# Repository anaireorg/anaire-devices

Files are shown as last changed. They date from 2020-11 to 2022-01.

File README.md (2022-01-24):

# Dispositivos ANAIRE: medidores de CO2 (NDIR), temperatura y humedad

**Enlace al medidor** [ *Anaire PiCO2*](https://github.com/anaireorg/anaire-devices/blob/main/Anaire.PiCO2/README.md)

---

[**Anaire**](http://www.anaire.org) - Somos un equipo de ingenieros españoles con la vocación de difundir de forma gratuita el conocimiento tecnológico que permita facilitar al máximo la monitorización del CO2 y contribuir así a la protección frente al contagio de COVID-19.

Diseñamos **medidores de CO2, temperatura y humedad**, optimizados para que cualquiera se los pueda fabricar por sí mismo y **aplicaciones hospedadas en la nube** para facilitar la monitorización de las medidas y la generación de alarmas que puedan alertar a la gente cuando los niveles de CO2 superen los umbrales de seguridad.

<p align="center">
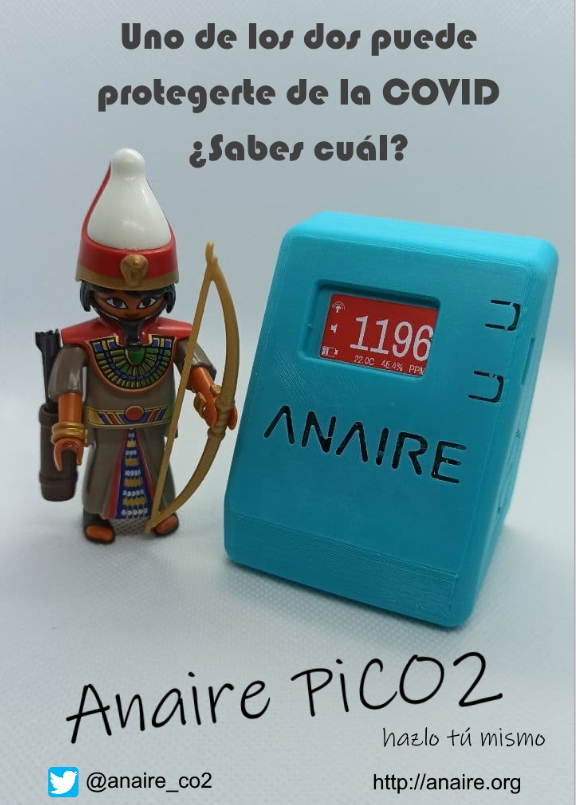
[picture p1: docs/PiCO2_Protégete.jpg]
  
</p>  

Nuestros dispositivos tienen las siguientes características principales:

- **Open source**, es decir, toda la información para su fabricación, tanto *hardware* como *software*, está disponible para su uso y modificación de acuerdo a los términos de la [licencia](LICENSE.md), siendo en todo momento totalmente gratuitos.

- Basados en sensores de CO2 de [*tecnología NDIR*](https://es.wikipedia.org/wiki/Sensor_de_Infrarrojo_No_Dispersivo), de bajo coste y alta precisión.

- **Hazlo tú mismo:** Fabricación muy sencilla, con mecanización mediante cajas fabricadas por impresión 3D para el alojamiento de los distintos componentes y su conexión mediante cables Dupont, minimizando el número de soldaduras necesarias.

- Conectados por WiFi a la [*aplicación en la nube Anaire Cloud*](https://github.com/anaireorg/anaire-cloud) para mostrar los valores instantáneos y el histórico de mediciones de CO2, temperatura y humedad, facilitando así el análisis de la información de las medidas y su correlación con protocolos de ventilación anti COVID-19, así como automatizaciones en forma de alarmas u otros eventos automáticos en función del valor de las medidas.

<p align="center">
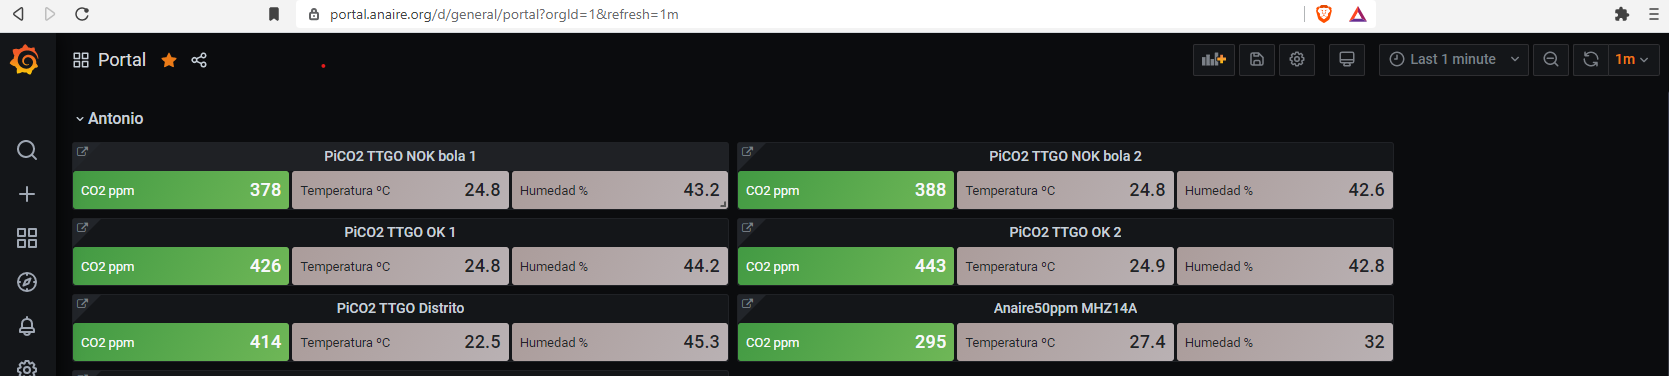
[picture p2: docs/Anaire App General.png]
  
</p>

<p align="center">
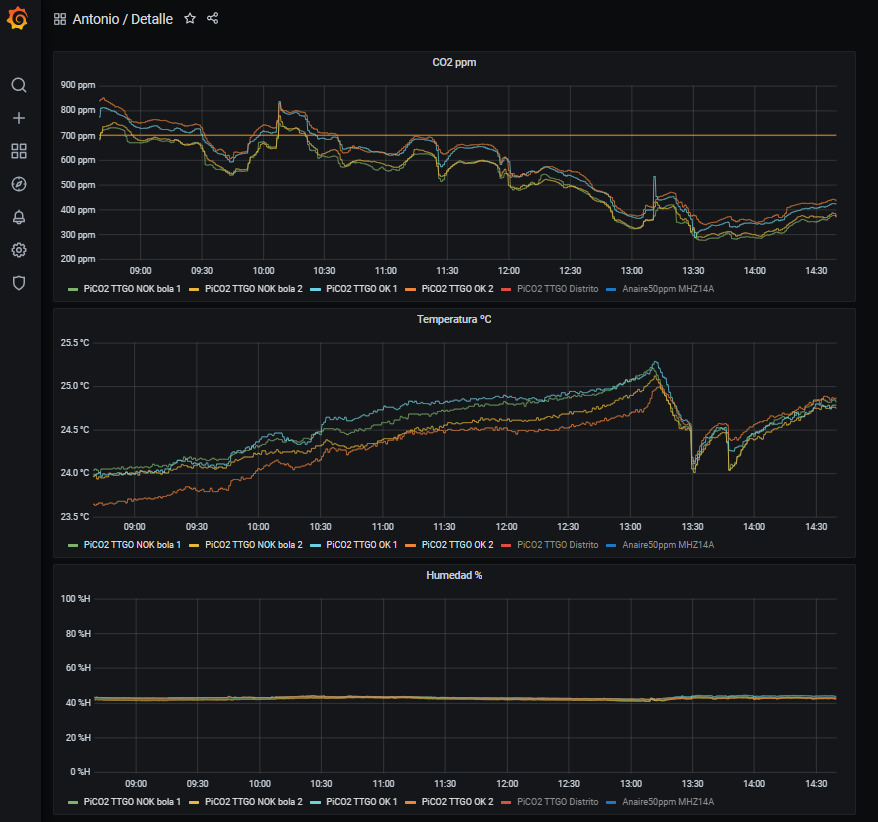
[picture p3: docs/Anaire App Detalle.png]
  
</p>

Hemos diseñado y documentado en detalle los siguientes dispositivos:

- [*Anaire PiCO2*](https://github.com/anaireorg/anaire-devices/blob/main/Anaire.PiCO2/README.md)
Nuestro último modelo, basado en el sensor de alta gama [*Sensirion SCD30*](https://www.sensirion.com/en/environmental-sensors/carbon-dioxide-sensors/carbon-dioxide-sensors-scd30/), con precición de 30 PPM (partes por millón), alarma acústica, pantalla a color y batería recargable mediante USB-C, lo que permite su uso portátil.
- [*Anaire 30/50ppm*](https://github.com/anaireorg/anaire-devices/blob/main/Anaire.30ppm-50ppm/README.md)
Nuestro primer dispositivo, con dos opciones: **Anaire 30ppm**, también basado en el mismo sensor [*Sensirion SCD30*](https://www.sensirion.com/en/environmental-sensors/carbon-dioxide-sensors/carbon-dioxide-sensors-scd30/), y **Anaire 50ppm**, que equipa el sensor [*Winsen MHZ14A*](https://www.winsen-sensor.com/sensors/co2-sensor/mh-z14a.html), de menor coste pero también menor precisión (50 PPM) y mayor tiempo de respuesta. Ambos modelos con alarma acústica, pantalla monocroma y alimentación mediante MicroUSB.

En este repositorio se publica información completa para la fabricación de los distintos modelos de medidor de CO2 Anaire, desde el código fuente hasta las especificaciones de componentes, cableados y opciones de montaje tanto en placa de prototipado como utilizando cajas de impresión 3D para la colocación de los componentes. La intención es que cualquier persona pueda encontrar aquí la información necesaria y suficiente para montar su propio sensor de CO2, con o sin conexión a la nube, sin necesidad de grandes conocimientos técnicos, como ayuda para combatir la pandemia causada por la COVID-19, contribuyendo así a preparar entornos más seguros, con mínimos niveles de CO2, que ayuden a prevenir contagios en entornos cerrados.

Toda la información se publica en formato *open source*, tanto los diseños hardware como el software (código fuente), con el ánimo de facilitar el uso y difusión de la tecnología todo lo posible. Con el mismo espíritu se tratan de resolver todas las incidencias reportadas en todos los canales donde la asociación está presente:

Página web: www.anaire.org  
Correo electrónico: anaire@anaire.org  
Canal de Youtube: https://www.youtube.com/c/AnaireCO2  
Twitter: @Anaire_co2  
Instagram: anaire_co2  
Facebook: @anaireco2  

---  

# Características detalladas

<p align="center">
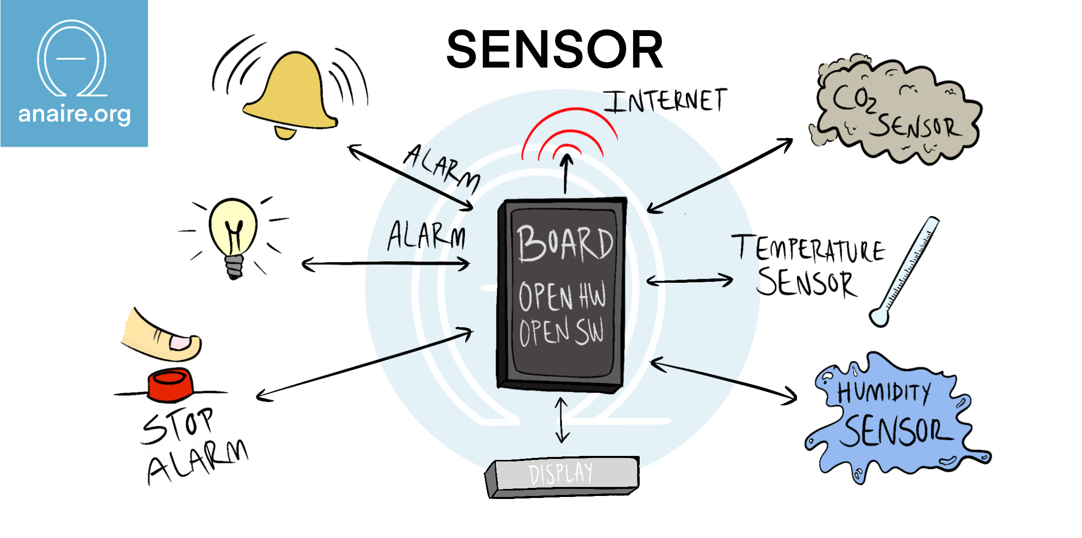
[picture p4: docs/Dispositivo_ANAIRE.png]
  
</p>  

* Medición de CO2 mediante sensores NDIR de alta precisión cada 5 o 10 segundos (Anaire 30/50ppm y Anaire PiCO2 respectivamente).
  * Adicionalmente se realizan de forma simultánea mediciones de temperatura y de humedad.
  * Cada 30 segundos las medidas se envían a la aplicación en la nube y pueden ser visualizadas en [portal.anaire.org](http://portal.anaire.org).
* Completamente open source, tanto hardware como software. Toda la información, tanto sobre este dispositivo como sobre la aplicación en la nube con la que se comunica, está disponible en los [repositorios de Anaire en github](https://github.com/anaireorg). Sin excepciones.  
* Alarma local, visual y acústica, cuando el nivel de CO2 sobrepasa los umbrales de aviso y alarma. Estos umbrales están fijados por defecto en 700ppm y 1.000ppm, pero los valores son configurables para cada dispositivo a través de la aplicación en la nube.
* La alarma acústica puede conmutarse localmente (encendido/apagado) mediante un botón en el dispositivo, desde el servidor web o desde la configuración del dispositivo en la nube.  
* Gestión de múltiples características de los dispositivos a través de los dos botones que equipan.
* Conexión a una red WiFi para el envío de las medidas a una aplicación desplegada en la nube con objeto de obtener los siguientes beneficios adicionales:
  * Monitorizar las medidas a través de internet desde cualquier tipo de dispositivo conectado.
  * Agregar la información de múltiples dispositivos permitiendo visualizar de forma simultánea el estado de todos ellos, siguiendo un código de colores sencillo (verde, amarillo y rojo) para indicar el estado actual de una organización con múltiples dispositivos. La idea es, sobre todo, poder monitorizar la medida del CO2 en centros de enseñanza, donde alumnos y profesores deben compartir espacios cerrados cotidianamente y durante periodos extendidos de tiempo.
  * Almacenar las medidas de CO2, temperatura y humedad durante al menos 15 días.
  * Facilitar el análisis de las medidas almacenadas, permitiendo el acceso al histórico de medidas de forma sencilla, para de este modo facilitar el análisis del funcionamiento de los protocolos de ventilación.  
  * Generar alarmas que puedan alertar a los responsables de una organización cuando los niveles de CO2 en cualquiera de los espacios gestionados alcancen valores peligrosos para la salud.
* Toda la información almacenada en la nube es accesible vía Internet, tanto en modo individual para cada dispositivo como en modo agregado en cuadros de mandos configurables con usuarios y permisos de visualización y de edición arbitrarios. De este modo se pueden definir distintos tipos de usuarios con distintos niveles de visualización de la información: personal del centro, alumnos, padres de alumnos, equipos de prevención de riesgos laborales, etc.  
* Para el acceso a la información sólo es preciso un dispositivo con conexión a Internet (ordenador, teléfono móvil, tableta, etc.), la dirección de acceso al dispositivo o a la organización, y un usuario y contraseña (en caso de que se hayan habilitado políticas de acceso).  
* Comunicación entre el dispositivo y la aplicación en la nube mediante protocolo MQTT.  
* Fabricación sencilla, soldando únicamente los cuatro pines necesarios en el sensor de CO2 y conectando los componentes mediante cables Dupont.
* Mecanización basada en cajas diseñadas a medida y fabricadas mediante impresoras 3D, que permiten ubicar de forma robusta los distintos componentes en los espacios preparados para ello en la caja. La caja es compatible para los distintos sensores, y alberga adicionalmente el display y el resto de los componentes de forma que sea muy fácil la lectura de las medidas.
* Alimentación mediante cables USB conectados a cualquier fuente de alimentación que proporcione más de 1A de corriente:
  * Cables MicroUSB en el caso de los dispositivos Anaire 30/50ppm
  * Cables USB-C para los dispositivos PiCO2
* Actualización remota de parámetros desde la aplicación en la nube:
  * Nombre del dispositivo
  * Umbral de aviso (700 ppm por defecto)
  * Umbral de alarma (1.000 ppm por defecto)
  * Activación y desactivación de la alarma acústica (activada por defecto)
  * Ajuste de offset de temperatura del sensor de CO2 (sólo para el Sensirion SCD30)
  * Ajuste de altitud del sensor de CO2 (sólo para el Sensirion SCD30)
  * Valor de referencia para la calibración forzada (420 ppm por defecto)
  * Realización de la calibración forzada
  * Activación y desactivación del mecanismo de autocalibración del sensor de CO2 (sólo para el Sensirion SCD30)
  * Actualización remota de *software* a la última versión disponible en este repositorio
  * Reinicio remoto del dispositivo
  * Restauración de todos los parámetros a los valores por defecto
  * Configuración de la dirección del servidor MQTT (url y puerto)
* Servidor Web desde donde se puede visualizar múltiples parámetros del dispositivo (versión de *software*, sensor equipado, etc.) e incluso realizar operaciones como la calibración de referencia.
* Portal cautivo para la configuración de la red WiFi, accesible mediante un botón en el dispositivo o desde el servidor web.

---

Recursos
---------

* [El País - Un salón, un bar y una clase: así contagia el coronavirus en el aire](https://elpais.com/ciencia/2020-10-24/un-salon-un-bar-y-una-clase-asi-contagia-el-coronavirus-en-el-aire.html)
* [Ventilando](http://www.ventilando.org/)
* [Comunidad de Madrid: Ventilación, climatización y COVID-19](https://www.comunidad.madrid/servicios/salud/ventilacion-climatizacion-covid-19)
* [Guía para ventilación de las aulas del CSIC](https://digital.csic.es/handle/10261/221538)
* [Transmisión de la COVID-19 por el aire (aerosoles). Por José Luis Jiménez.](https://www.youtube.com/watch?v=uI8ODCxrNMU&t=4s)
* [José Luis Jiménez, El País: La covid se transmite a través de aerosoles: ya es el momento de actuar, tenemos suficientes pruebas](https://elpais.com/ciencia/2020-08-18/la-covid-se-transmite-a-traves-de-aerosoles-ya-es-el-momento-de-actuar-tenemos-suficientes-pruebas.html)
* [Summary of the Evidence For and Against the Routes of Transmission of SARS-CoV-2](https://docs.google.com/presentation/d/11rY9tQtkFaV_M4N-hf5qp1_Xtuw8JYb4Qvv5e7BEmcc/edit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)
* [Aireamos: Medidores de CO2 disponibles en España](https://www.aireamos.org/medidores/)
* [Así se ven los aerosoles en un ascensor, una tienda, una oficina y un bar: ¿cómo se transmite el coronavirus?](https://amp.rtve.es/noticias/20210312/coronavirus-aerosoles-imagenes/2081740.shtml)
* [Daily global CO2](https://www.esrl.noaa.gov/gmd/ccgg/trends/gl_trend.html)
* [IAQ Rating Index](http://www.iaquk.org.uk/ESW/Files/IAQ_Rating_Index.pdf)

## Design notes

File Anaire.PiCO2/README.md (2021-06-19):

# Anaire PiCO2

*@2021 Anaire www.anaire.org*

---

<p align="center">
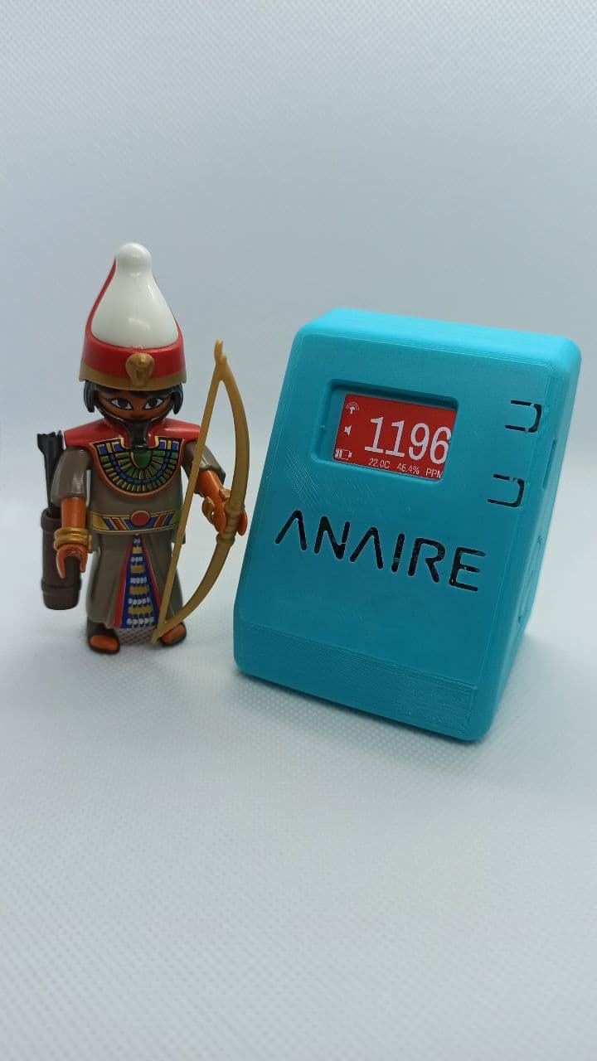
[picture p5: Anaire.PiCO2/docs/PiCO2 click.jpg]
  
</p>  

# Tabla de contenidos
[1. Hardware](#id1)  
[2. Software](#id2)  
[3. Fabricación](#id3)  
[4. Configuración](#id4)  
[5. Uso](#id5)  
[6. Diagnóstico](#id6)  

---

# 1. Hardware

El medidor Anaire PiCO2 es un dispositivo basado en un microcontrolador ESP32 en una tarjeta de control [LILYGO® TTGO T-Display ESP32 WiFi And Bluetooth](https://github.com/Xinyuan-LilyGO/TTGO-T-Display), que proporciona también conectividad WiFi y Bluetooth, y permite su programación desde el IDE de Arduino. La tarjeta tiene integrado un display en color para mostrar las mediciones e indicaciones de estado. Adicionalmente el dispositivo equipa un zumbador para poder emitir alertas sonoras y una batería recargable para facilitar la movilidad.

Para realizar las medidas se conecta un sensor de CO2 de tecnología NDIR, que adicionalmente realiza medidas de temperatura y humedad:  [*Sensirion SCD30*](https://www.sensirion.com/en/environmental-sensors/carbon-dioxide-sensors/carbon-dioxide-sensors-scd30/). El Sensirion SCD30 es un sensor de alta calidad y gran velocidad de reacción: tiene mayor precisión que la mayoría de los sensores de su mismo tipo, 30 ppm frente a los 50 ppm del Winsen MH-Z14A; incorpora sensor de temperatura y humedad, con lo que no hay que añadir un sensor adicional para medir temperatura y humedad, facilitando el montaje del medidor. Además de permitir mecanismos de compensación por altitud y temperatura; tiene un mecanismo de autocalibración más robusto, que hace uso de las mediciones de los últimos 30 días, en lugar de las últimas 24 horas, como en el caso del MH-Z14A. Su respuesta es también más rápida ante cambios atmosféricos (por ejemplo, al introducir ventilación en un espacio cerrado). Los inconvenientes del Sensirion SCD30 son que tiene un precio más elevado, que es más frágil durante su manipulación y que tiene menos opciones de compra y, normalmente, mayores plazos de entrega. Para comprar el Sensirion SCD30 hay que recurrir normalmente a plataformas especializadas en componentes electrónicos.

La alimentación del dispositivo se realiza directamente a través del puerto USB-C de la tarjeta de control [LILYGO® TTGO T-Display ESP32 WiFi And Bluetooth](https://github.com/Xinyuan-LilyGO/TTGO-T-Display), el mismo que se utiliza para programarla y para comunicarse con ella. La batería incorporada se carga automáticamente cuando se conecta un cable USB-C alimentado. Se recomienda utilizar fuentes de alimentación (enchufes USB, puertos USB en ordenadores, etc.) que puedan proporcionar al menos 1.000 mA.   

A continuación, se enumeran los elementos citados:

* Tarjeta de control basada en microcontrolador ESP32 [LILYGO® TTGO T-Display ESP32 WiFi And Bluetooth](https://github.com/Xinyuan-LilyGO/TTGO-T-Display)  

<p align="center">
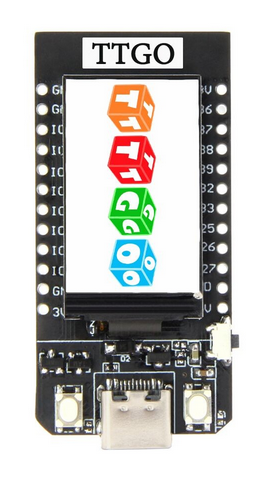
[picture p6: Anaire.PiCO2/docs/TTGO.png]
    
</p>

* Sensor de CO2, temperatura y humedad [*Sensirion SCD30*](https://www.sensirion.com/en/environmental-sensors/carbon-dioxide-sensors/carbon-dioxide-sensors-scd30/). Para la conexión del sensor de CO2 es preciso conectar 4 pines y soldarlos en las posiciones indicadas en el proceso de fabricación. Se pueden comprar pines como [los que aparecen en este enlace](https://www.amazon.es/Pin-Header-Way-Straight-Pitch/dp/B00QXBRCKG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), por ejemplo, y cortar trozos de 4 pines con un alicate de corte o unas tijeras.

<p align="center">
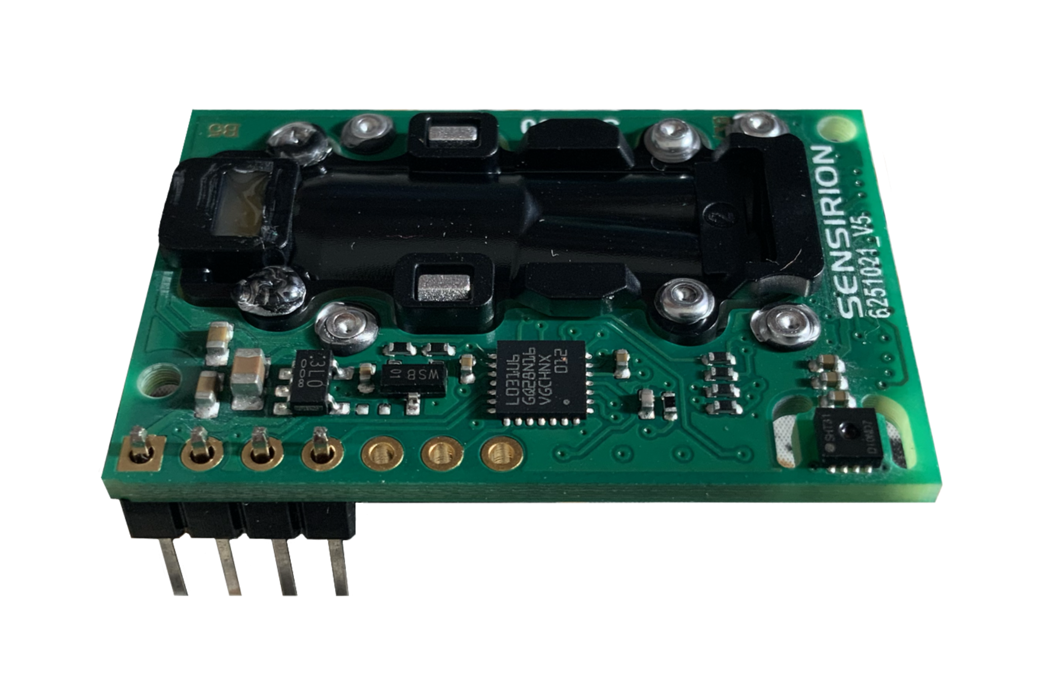
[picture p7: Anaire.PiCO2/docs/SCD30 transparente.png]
  
</p>  

* Caja -Anaire Box- para impresora 3D. Los ficheros para la impresión se pueden encontrar en [este enlace](https://www.thingiverse.com/thing:4854504).

<p align="center">
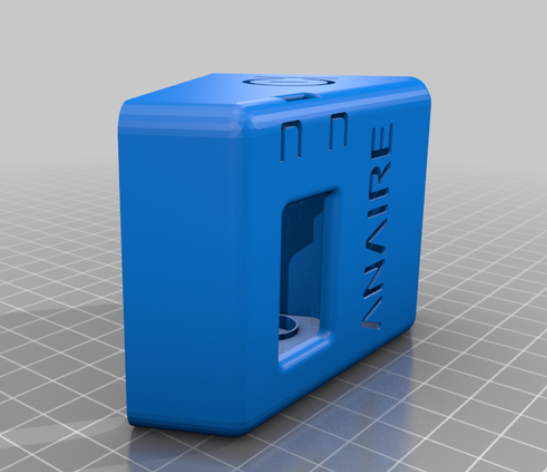
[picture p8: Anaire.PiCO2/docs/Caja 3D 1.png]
  
</p>    
<p align="center">
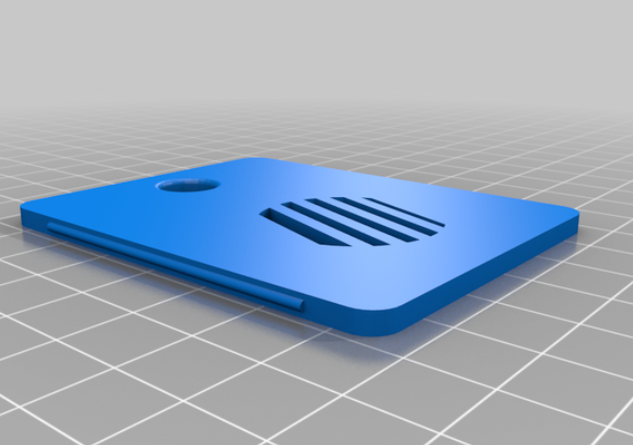
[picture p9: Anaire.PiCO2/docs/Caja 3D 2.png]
  
</p>
<p align="center">
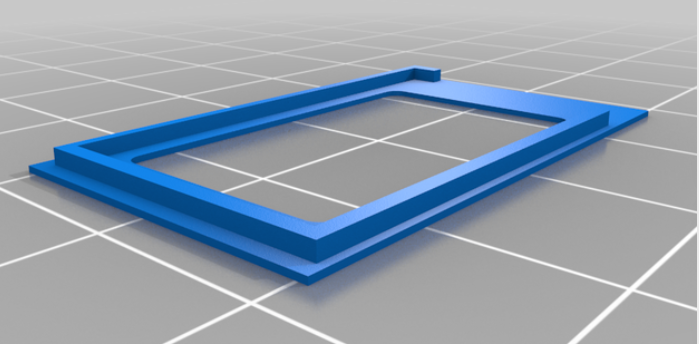
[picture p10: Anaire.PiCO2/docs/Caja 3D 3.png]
  
</p>  

* Zumbador [- AZDelivery Active Buzzer](https://www.az-delivery.de/es/products/buzzer-modul-aktiv?_pos=2)  

<p align="center">
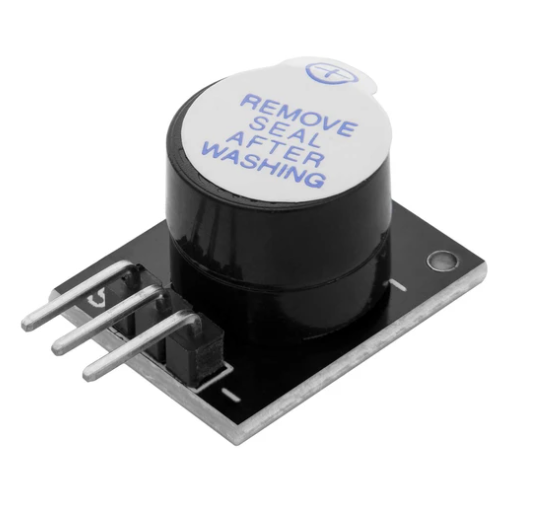
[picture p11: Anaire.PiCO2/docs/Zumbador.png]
    
</p>

* [Batería Recargable de Litio con conector Micro JST 1.25 3.7V y al menos 1.000 mAh de capacidad](https://www.amazon.es/dp/B087LTZW61/ref=cm_sw_r_cp_awdb_imm_BPVY2QA8X3P5GB9NQ55C)

<p align="center">
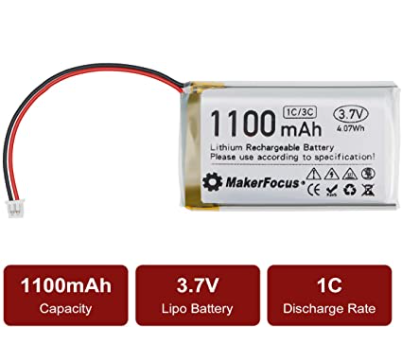
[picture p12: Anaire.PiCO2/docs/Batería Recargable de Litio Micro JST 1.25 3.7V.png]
  
</p>

* [Cables Dupont hembra-hembra de 10cm de longitud](https://es.aliexpress.com/item/32223527499.html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)

<p align="center">
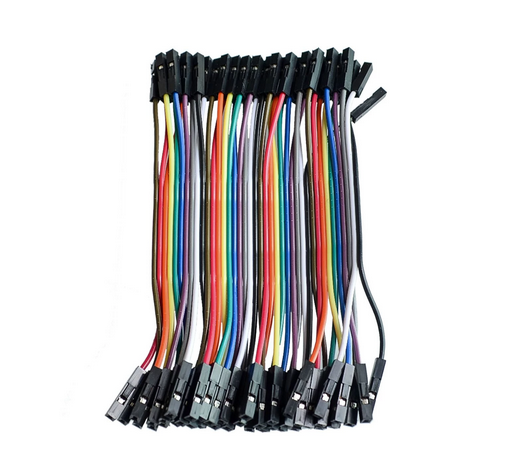
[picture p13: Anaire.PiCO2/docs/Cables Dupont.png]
  
</p>

* Será necesario un cable válido para conectar desde un puerto USB del ordenador al puerto Micro USB-C de la tarjeta TTGO T-Display, para poder cargar el software del dispositivo. Este mismo cable puede ser utilizado para la alimentación eléctrica desde un ordenador, o desde un enchufe USB o incluso desde una batería portátil USB. También podría utilizarse, una vez cargado el software, cualquier otro tipo de dispositivo que tenga un conector USB-C y proporcione al menos 1.000 miliamperios. Por ejemplo, [este cable](https://www.amazon.es/dp/B01N4OKUB8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), o [este alimentador](https://www.amazon.es/UGREEN-Cargador-Delivery-Ultrarrapido-iPhone/dp/B07QRQTKCZ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)

# 2. Software

El software se puede cargar en el dispositivo de dos formas: 

- Utilizando el [entorno de desarrollo (IDE) de Arduino](https://www.arduino.cc/en/software), exactamente igual que una tarjeta arduino. Hay que instalar algunos componentes de software adicionales en el entorno de Arduino, principalmente diversas librerías. La descripción completa de la instalación del entorno de *software* se puede encontrar al inicio del archivo de código fuente del dispositivo medidor [anaire.PiCO2.ino](https://github.com/anaireorg/anaire-devices/blob/main/Anaire.PiCO2/anaire.PiCO2/anaire.PiCO2.ino).

- Mediante un mecanismo sencillo basado en la carga del binario ya compilado en la tarjeta TTGO T-Display, como se describe más adelante, en el apartado de fabricación.

En cualquier caso, la instalación del entorno completo de desarrollo no será necesaria si no se requiere hacer modificaciones en el software. 

Para cualquiera de las dos opciones será necesario instalar previamente en un ordenador con sistema operativo Windows10 el [driver USB-UART](https://www.silabs.com/developers/usb-to-uart-bridge-vcp-drivers) (conversión USB a puerto serie) para poder comunicarse con la tarjeta TTGO T-Display.

# 3. Fabricación

El montaje que se propone pretende simplificar al máximo el proceso de fabricación, manteniendo las máximas prestaciones técnicas. Los componentes se encajan en la caja de impresión 3D, y las conexiones se realizan mediante cables Dupont hembra-hembra, minimizando así las necesidades de soldadura. Sólo será necesario soldar 4 pines en el sensor SCD30 y 7 pines en la tarjeta TTGO T-Display (en el caso de que no se haya comprado con los pines ya soldados).

## Esquema de conexiones:  
<p align="center">
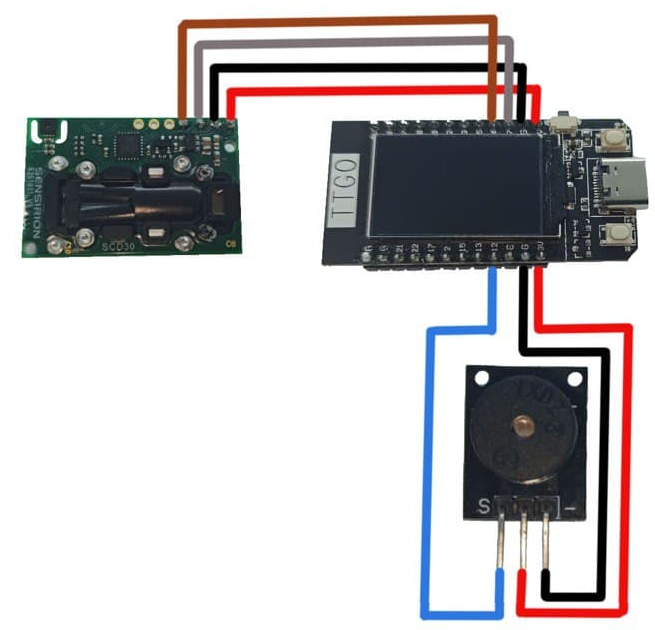
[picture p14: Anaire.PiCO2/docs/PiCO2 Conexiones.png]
  
</p>  

## Detalle del sensor SCD30  
Hay que soldar 4 pines como se muestra en la siguiente imagen  
<p align="center">
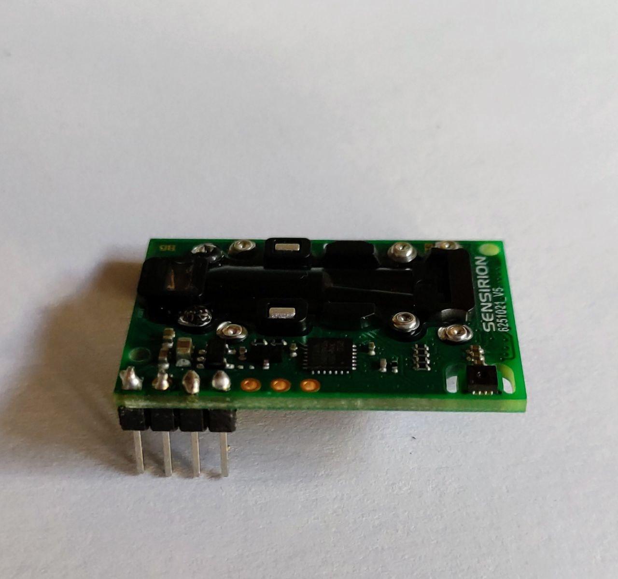
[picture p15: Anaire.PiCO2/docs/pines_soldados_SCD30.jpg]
  
</p>  

## Montaje final  

Recomendamos que primero se conecten los componentes, se cargue el *software*, siguiendo las instrucciones del apartado siguiente, y se verifique así el funcionamiento del medidor.

<p align="center">
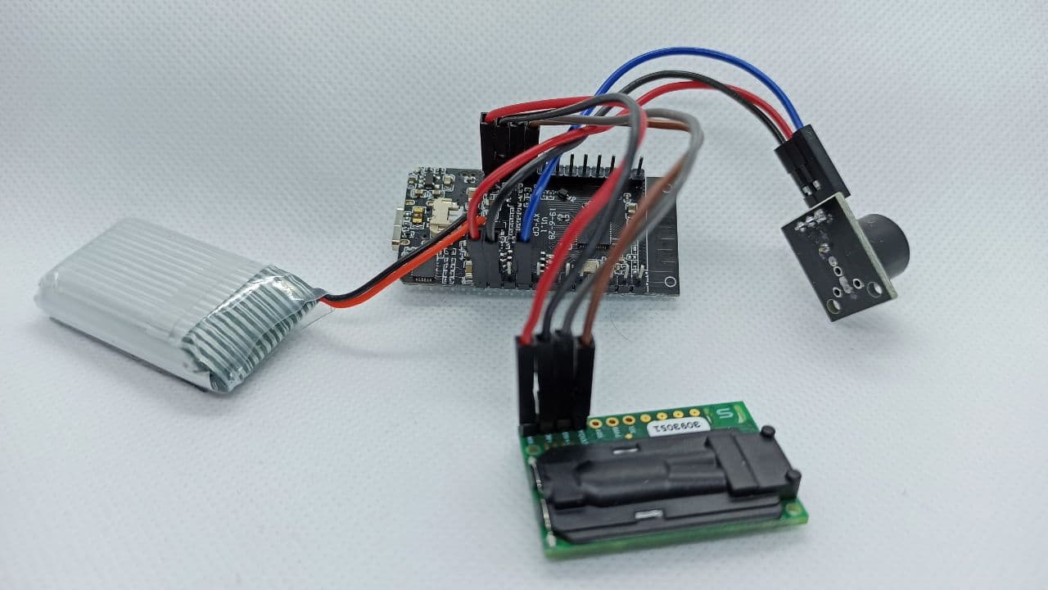
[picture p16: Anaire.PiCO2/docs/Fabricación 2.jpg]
  
</p>  
<p align="center">
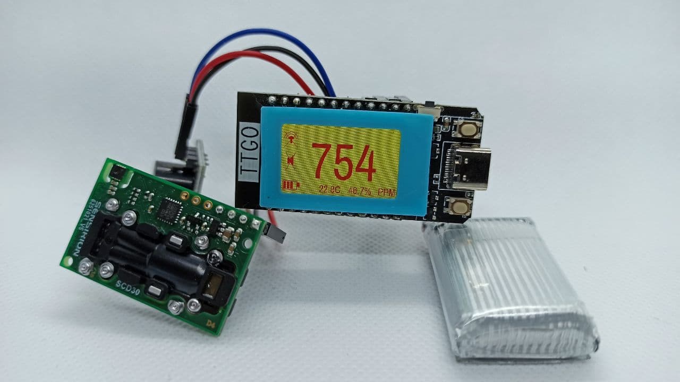
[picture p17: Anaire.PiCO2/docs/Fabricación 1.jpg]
  
</p>  

A continuación, se colocan los componentes mecánicamente en su posición dentro de la caja, y se vuelve a verificar el funcionamiento correcto.

Para ello, primero se coloca la pieza cuadrada pequeña alrededor de la pantalla, como se muestra en la imagen:

<p align="center">
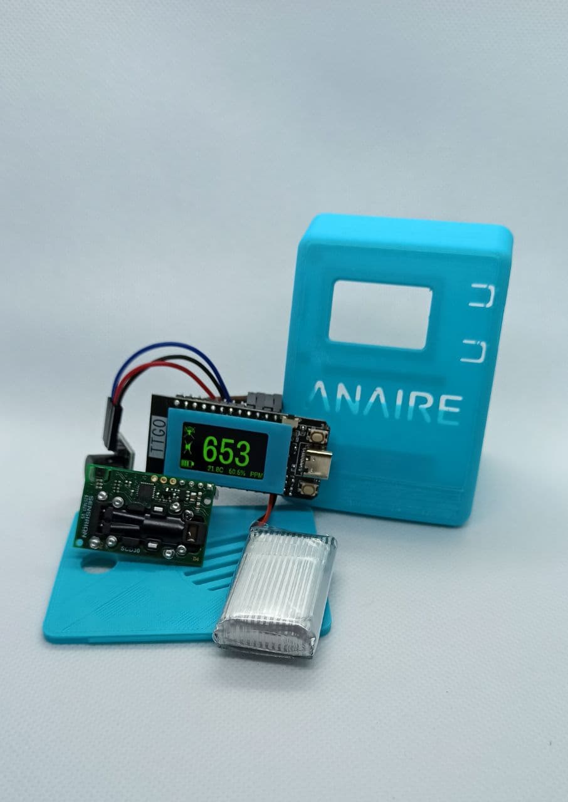
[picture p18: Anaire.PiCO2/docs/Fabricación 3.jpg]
  
</p>

Luego, se inserta la placa ajustando el conector para la alimentación y se encaja en la pestaña que hay en el lado opuesto. Se ajusta el zumbador en el hueco circular del lateral y, finalmente, se ajusta el sensor en las pestañas que hay debajo de donde va colocada la placa.

<p align="center">
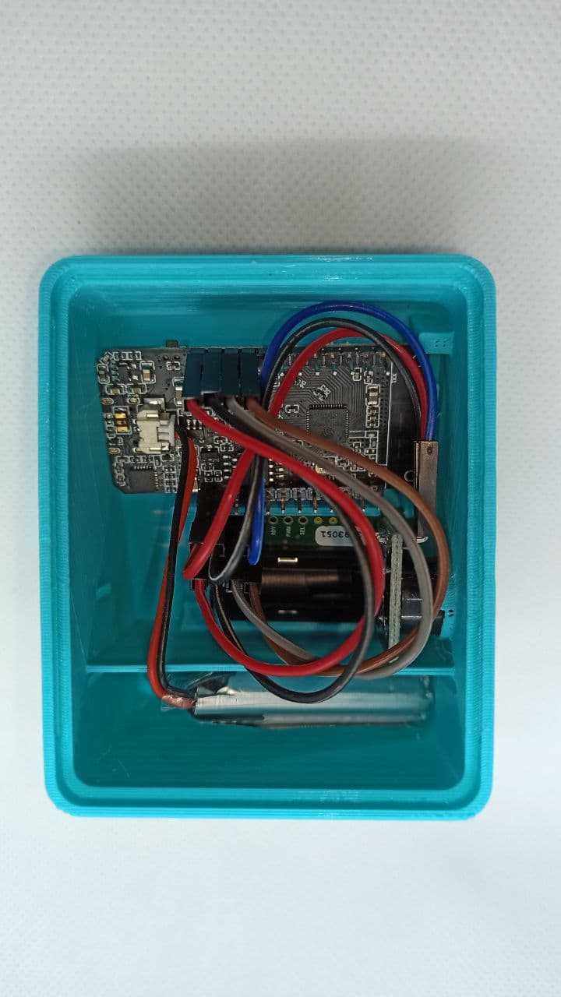
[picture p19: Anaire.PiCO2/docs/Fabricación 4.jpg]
  
</p>

Finalmente se debe proceder a la conexión a la red WiFi y la calibración de referencia del sensor. Se puede activar el mecanismo de autocalibración del SCD30, pero para que funcione correctamente hay que tenerlo encendido durante una semana garantizando su exposición al aire libre (se trata de medir un valor mínimo de CO2) durante al menos una hora al día.

El siguiente vídeo muestra de forma detallada el proceso montaje:

Montaje Anaire PiCO2 (https://youtu.be/GUXPi4h12Kw)

## Carga del software

Para la carga del software hay dos opciones: carga del binario compilado, o carga desde el código fuente. Como ya se ha explicado anteriormente, si no se desea modificar el software se recomienda la primera opción, ya que es mucho más sencilla y rápida.

En cualquiera de los dos casos es preciso instalar previamente en un ordenador con sistema operativo Windows 10 el [driver USB-UART](https://www.silabs.com/developers/usb-to-uart-bridge-vcp-drivers) (conversión USB a puerto serie) para poder comunicarse con la tarjeta TTGO T-Display.

### Carga del binario compilado
Estas instrucciones son únicamente válidas para ordenadores con el sistema operativo Windows 10.

Asegure que se tiene en un directorio los siguientes archivos, disponibles en la carpeta [anaire.PiCO2](https://github.com/anaireorg/anaire-devices/tree/main/Anaire.PiCO2/anaire.PiCO2):
  * anaire.PiCO2.ino.esp32.bin
  * boot_app0.bin
  * bootloader_qio_80m.bin
  * esptool.exe
  * flash_device.bat

Ejecute los siguientes pasos en esa carpeta:
1. Conecte el medidor PiCO2 al ordenador mediante un cable USB-C. En el administrador de dispositivos de windows podrá identificar el puerto COM asignado por el sistema operativo al medidor PiCO2.

<p align="center">
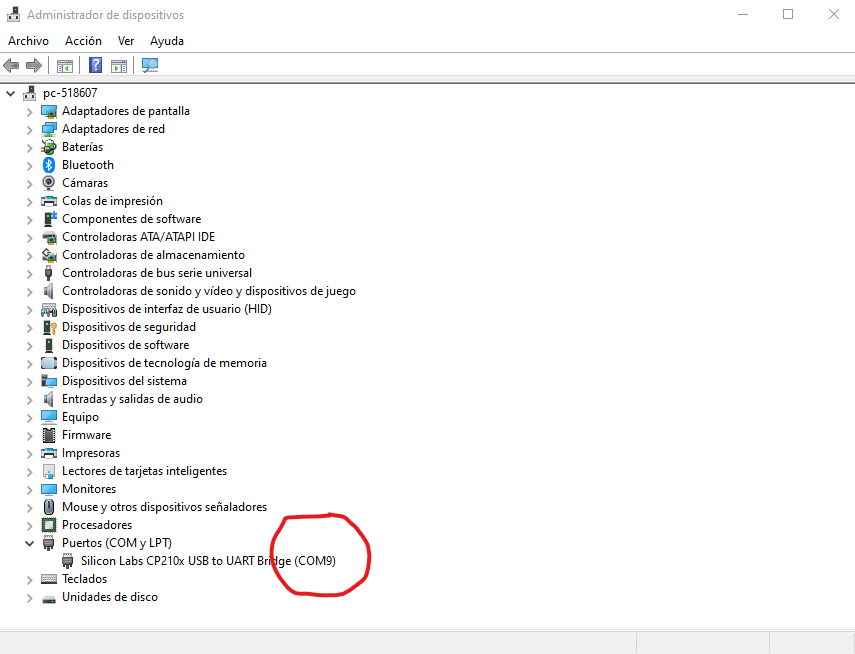
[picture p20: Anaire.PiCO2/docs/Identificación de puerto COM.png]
  
</p>

2. Haga click derecho en el archivo [flash_device.bat](https://github.com/anaireorg/anaire-devices/blob/main/Anaire.PiCO2/anaire.PiCO2/flash_device.bat) y seleccione la opción de *editar*

3. Donde pone *--port COMXX* sustituya el puerto COMXX para poner el que haya identificado previamente en el paso 1, seleccione *archivo->guardar* y cierre la ventana

<p align="center">
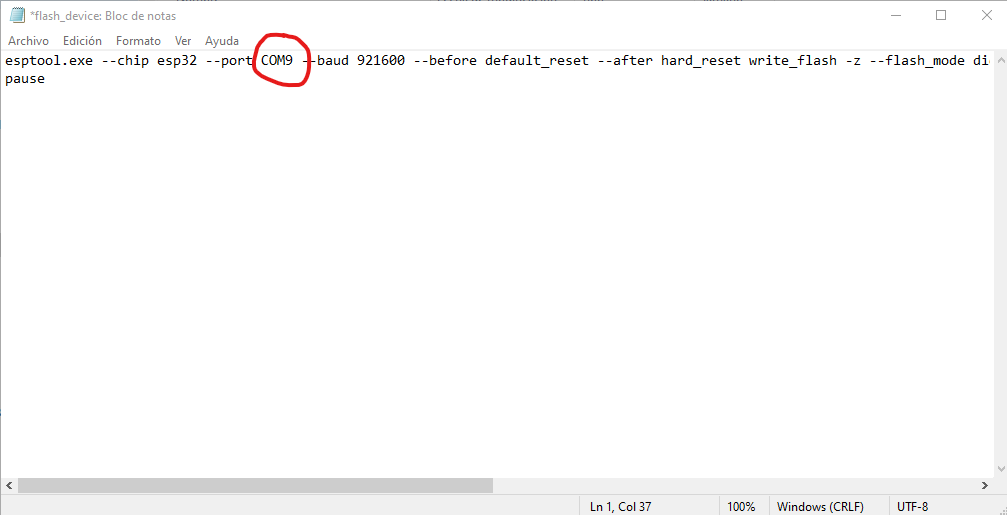
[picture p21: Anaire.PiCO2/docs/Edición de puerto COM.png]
  
</p>

4. Haga doble click en el archivo [flash_device.bat](https://github.com/anaireorg/anaire-devices/blob/main/Anaire.PiCO2/anaire.PiCO2/flash_device.bat). Al acabar la ejecución pedirá que se pulse cualquier tecla para cerrar la ventana. El medidor PiCO2 arrancará con la última versión de *software* disponible en el archivo [anaire.PiCO2.ino.esp32.bin](https://github.com/anaireorg/anaire-devices/blob/main/Anaire.PiCO2/anaire.PiCO2/anaire.PiCO2.ino.esp32.bin)

<p align="center">
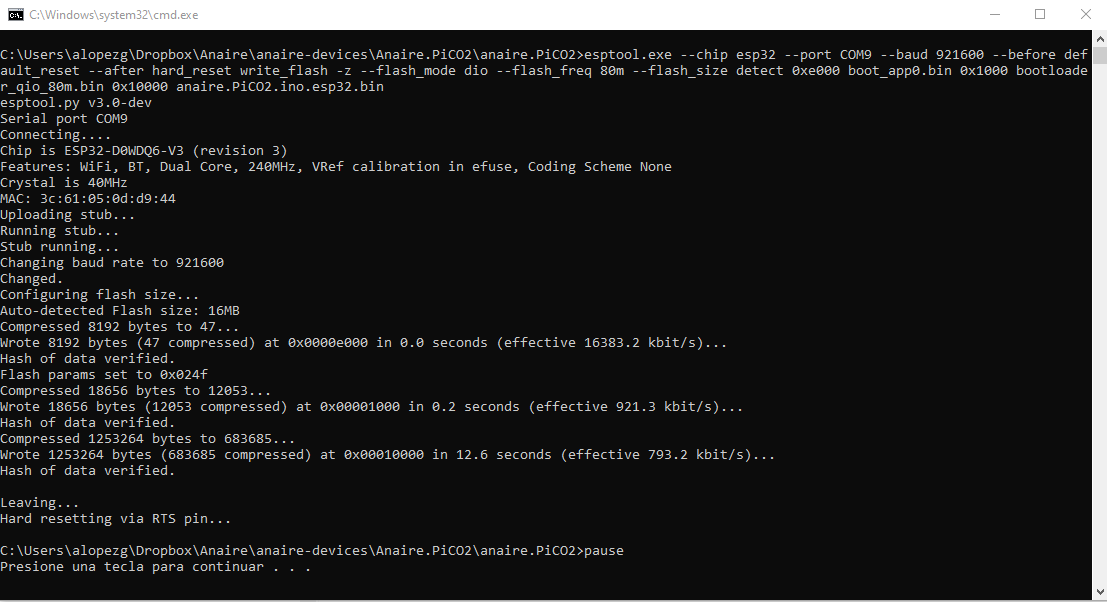
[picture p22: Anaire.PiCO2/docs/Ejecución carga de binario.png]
  
</p>

### Carga desde el código fuente

1. Instale el [entorno de desarrollo de Arduino](https://www.arduino.cc/en/software).

2. Instale los componentes de software requeridos en el entorno de Arduino, tal como se describe al inicio del archivo de código fuente del dispositivo medidor [anaire.PiCO2.ino](https://github.com/anaireorg/anaire-devices/blob/main/Anaire.PiCO2/anaire.PiCO2/anaire.PiCO2.ino).
Para ello realice los siguientes pasos:

3. Cargue el programa [anaire.PiCO2.ino](https://github.com/anaireorg/anaire-devices/blob/main/Anaire.PiCO2/anaire.PiCO2/anaire.PiCO2.ino) en el IDE de Arduino utilizando la opción *Archivo->Abrir*

4. Conecte mediante un cable USB-C el PiCO2 al ordenador

5. Seleccione el puerto apropiado en *Herramientas -> Puerto*. Si sólo tiene un PiCO2 conectado, sólo debería aparecer una opción para seleccionar. Si no aparece ninguna, o bien no se ha instalado correctamente el [driver USB-UART](https://www.silabs.com/developers/usb-to-uart-bridge-vcp-drivers), o bien el cable USB-C o la tarjeta TTGO T-Display son defectuosos.

6. Seleccione el esquema de particionado de la tarjeta tal como se muestra en la imagen a continuación:

<p align="center">
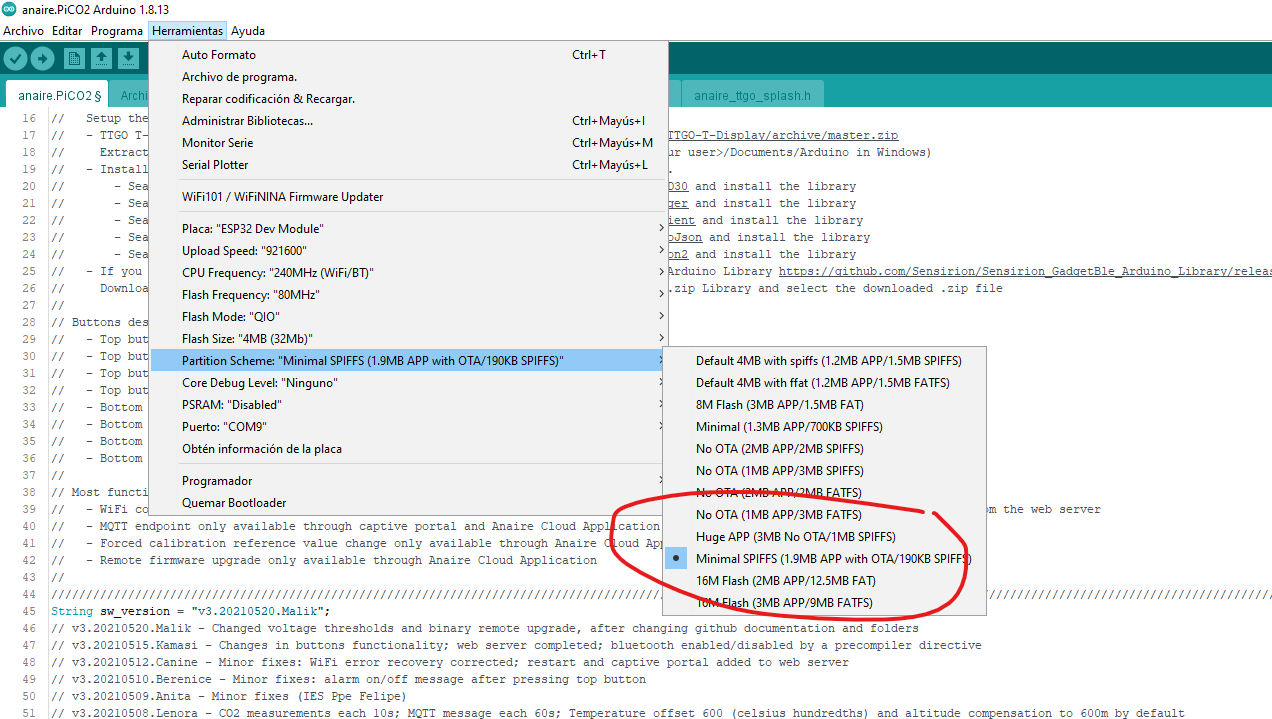
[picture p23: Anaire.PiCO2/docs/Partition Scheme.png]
  
</p>

7. Presione el botón de carga, que se indica en el IDE con una flecha apuntando hacia la derecha, y espere a que se compile y se descargue el software en la tarjeta TTGO T-Display.

<p align="center">
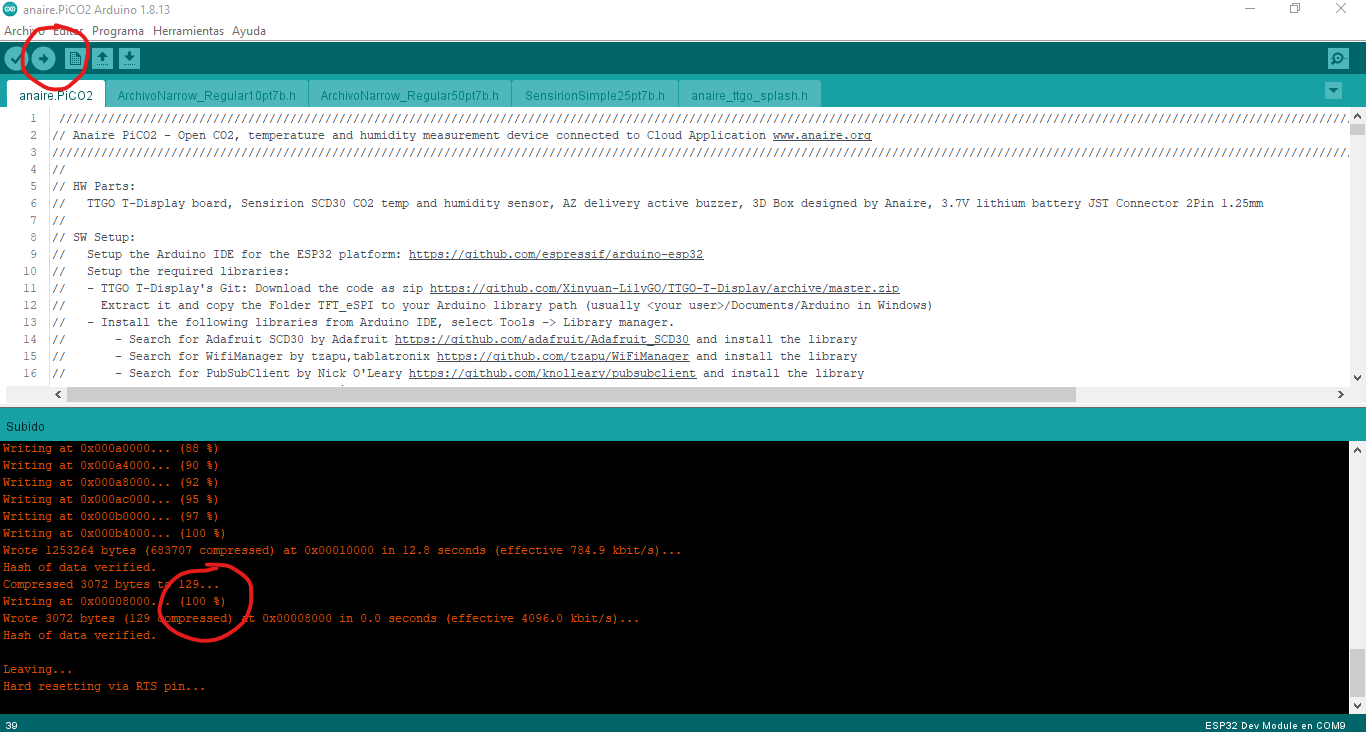
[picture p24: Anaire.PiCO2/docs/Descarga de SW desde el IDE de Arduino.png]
  
</p>

El proceso puede durar varios minutos, dependiendo de la potencia de cálculo del ordenador. Al término del proceso en el IDE de Arduino se mostrará un mensaje indicando que se ha escrito el 100% del programa en la tarjeta, y el dispositivo PiCO2 se reiniciará mostrando durante varios segundos la imagen de Anaire en la pantalla, para a continuación comenzar a mostrar medidas cada 10 segundos.

# 4. Configuración

Para completar la configuración del dispositivo PiCO2 hay que conectarlo a una red WiFi y realizar la calibración de referencia.

## Configuración de la conexión WiFi
   * Pulse 3 veces consecutivas el botón superior para arrancar el portal cautivo, es decir, una red WiFi y un servidor web que le permiten modificar la configuración del PiCO2.
   * Se creará una red WiFi abierta con el nombre AnaireWiFi_XXXXXX, donde XXXXXX es el identificador del dispositivo. La pantalla mostrará sobre fondo naranja el nombre de la red WiFi creada.
   * Conecte a esa red con un PC, tablet o teléfono móvil
   * Una vez conectado a la red introduzca la dirección IP **192.168.4.1** en su navegador. De esta forma se accede al portal de configuración del dispositivo
   * En el portal puede escoger una red WiFi entre las detectadas, e introducir la contraseña de la red. Pulse en el botón *Save* tras escribir la contraseña.
     * Si todo ha ido correctamente el dispositivo se reiniciará con conexión a la nueva red WiFi y podrá ver el icono de la conexión WiFi en la esquina superior izquierda de la pantalla.
     * En caso de utilizar encriptación WPA2-Enterprise deberá espera a que el PiCO2 se reinicie automáticamente al cabo de 2 minutos.
     * Si ha habido algún problema de conexión (por ejemplo, si se ha introducido una contraseña errónea), el dispositivo mostrará el icono de la red WiFi en la esquina superior izquierda del display tachado, y deberá repetir el procedimiento.
   * En el portal se puedan modificar otros parámetros de configuración, como un usuario y contraseña para redes WPA2-Enterprise, o la conexión a la aplicación en la nube (MQTT server y puerto).

## Calibración de referencia
Sitúe el medidor PiCO2 al aire libre, protegido del sol, de otras fuentes de luz intensas y de las corrientes de aire (por ejemplo, dentro de una caja de cartón en el alféizar de la ventana), y arranque el proceso de calibración mediante alguno de los siguientes métodos:
- Presione el botón inferior durante más de 1 segundo
- Identifique la dirección IP del dispositivo pulsando brevemente el botón superior, e introduzca la dirección en un navegador de un dispositivo conectado a la misma red WiFi. En el servidor web haga click en el enlace que permite iniciar la calibración de referencia del dispositivo.
- Acceda a la aplicación en la nube, entrando en la opción de editor de parámetros. Para ello debe tener permisos de administrador en la aplicación. Active la opción denominada *Forced calibration* y haga click en el botón *Update*. de esta forma podrá iniciar la calibración a través de Internet.

En cualquiera de los métodos anteriores la pantalla del PiCO2 se pondrá de color naranja e iniciará una cuenta atrás de 60 segundos para indicar el tiempo restante hasta que se complete la calibración forzada. No interfiera con el dispositivo, ni lo manipule o lo acerque a fuentes de CO2 (como la respiración) mientras dure la cuenta atrás.

Al término del proceso el dispositivo se reiniciará y volverá a tomar medidas, tomando como referencia el valor de 420 ppm (este valor se puede modificar desde la aplicación en la nube). El proceso no puede ser interrumpido, deberá esperar a su término al cabo de 60 segundos en cualquier caso.

# 5. Uso

Para empezar a realizar medidas sólo tiene que alimentar el PiCO2 con un cable USB-C. Cuando la batería ya esté parcialmente cargada podrá incluso prescindir de la alimentación durante varias horas y llevarse el PiCO2 para realizar medidas itinerantes. Un icono con forma de pila en la parte inferior izquierda de la pantalla le mostrará la indicación del nivel de carga disponible.

En caso de que el valor medido de CO2 supere el umbral de aviso, el dispositivo empezará a emitir un pitido intermitente, y el fondo de la pantalla se mostrará de color amarillo. Si supera el valor del umbral de alarma, el pitido intermitente será más largo, y el fondo de la pantalla se mostrará de color rojo.

Los valores por defecto de los umbrales son 700 PPM para el aviso y 1.000 PPM para la alarma. Estos valores se pueden modificar desde la aplicación de Anaire en la nube.

Si se desea detener la alarma acústica presione durante más de un segundo el botón superior. Vuelva a hacer lo mismo cuando desee activarla de nuevo. En el display se mostrará el estado de la alarma mediante un icono que muestra un altavoz (activa), o un altavoz tachado (desactivada).

El PiCO2 tiene un identificador único (ID) generado a partir de la dirección MAC de la interfaz WiFi de cada tarjeta TTGO T-Display. Este ID es un texto hexadecimal de 6 caracteres, utilizado para el acceso a las medidas en Internet y la integración del medidor en la aplicación en la nube de Anaire. No es preciso realizar ninguna configuración sobre este identificador, se genera de forma automática para cada tarjeta TTGO. Este ID se utiliza para identificar las medidas del dispositivo en la aplicación en la nube, así como para identificar la red WiFi que genera el propio PiCO2 cuando se arranca el modo de configuración.

## Botones
El PiCO2 tiene dos botones a la derecha de la pantalla, uno superior y otro inferior. Puede usar los botones para realizar las siguientes funciones:

### Botón superior
- Pulsación corta - Muestra información del dispositivo: ID, versión de *software*, red WiFi, dirección IP, dirección MAC, potencia WiFi (RSSI), estado de la alarma acústica (SÍ/NO), estado de la calibración (forzada/auto)
- Pulsación larga (durante más de 1 segundo) - Conmuta el estado de la alarma acústica
- Doble pulsación - Duerme el dispositivo para ahorrar batería cuando no sea necesario utilizarlo; para despertarlo, vuelva a pulsar el botón superior
- Triple pulsación - Arranca el portal cautivo que permite configurar la conexión WiFi y la dirección del servidor MQTT de la aplicación Anaire en la nube a la que enviar las medidas

### Botón inferior
- Pulsación corta - Muestra información del uso de los botones
- Pulsación larga (más de 1 segundo) - Inicia el proceso de calibración forzada. Este proceso dura 60 segundos y no se puede interrumpir.
- Doble pulsación -  Reinicia el PiCO2
- Triple pulsación - Activa el mecanismo de autocalibración del PiCO2, dejando sin efecto la calibración de referencia que se haya podido realizar anteriormente.

## Servidor Web

Si se conecta con un dispositivo a la misma red WiFi a la que esta conectado el medidor PiCO2, accediendo a la dirección IP del medidor mediante un navegador se puede acceder al servidor web del PiCO2, pudiendo así acceder a información detallada del dispositivo, a las últimas medidas, e incluso pudiendo realizar diversas acciones de configuración, como se puede ver en la siguiente imagen:

<p align="center">
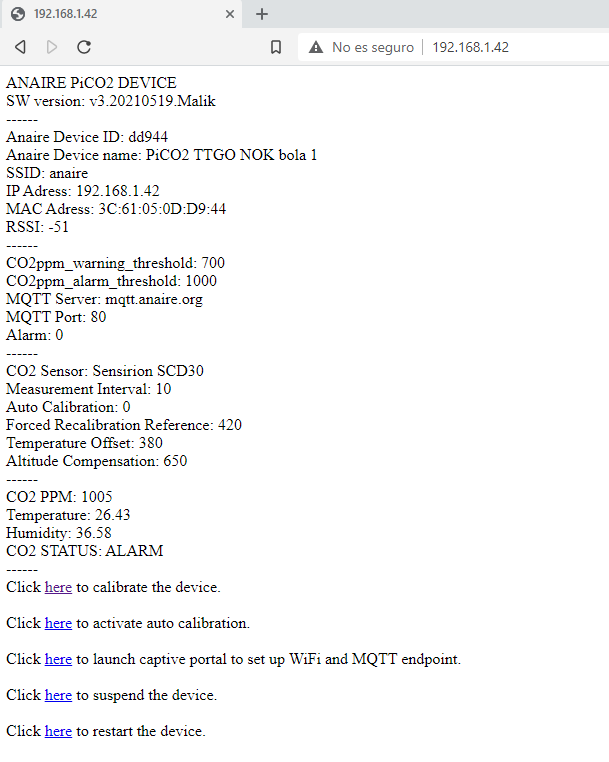
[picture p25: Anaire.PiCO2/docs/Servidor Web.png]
  
</p>

## Acceso por internet a las medidas
Si se ha conectado el PiCO2 a una red WiFi con acceso a internet y se han dejado los valores por defecto de conexión a la aplicación en la nube, se puede acceder a los valores medidos por el dispositivo en los siguientes enlaces. Sustituya *ID_del_dispositivo* por el ID del PiCO2 en cuestión para acceder a las medidas:

* Valores actuales en modo kiosko (modo muy práctico para visualizar las medidas en un teléfono móvil por ejemplo):  
    https://portal.anaire.org/sensor/ID_del_dispositivo/

    <p align="center">
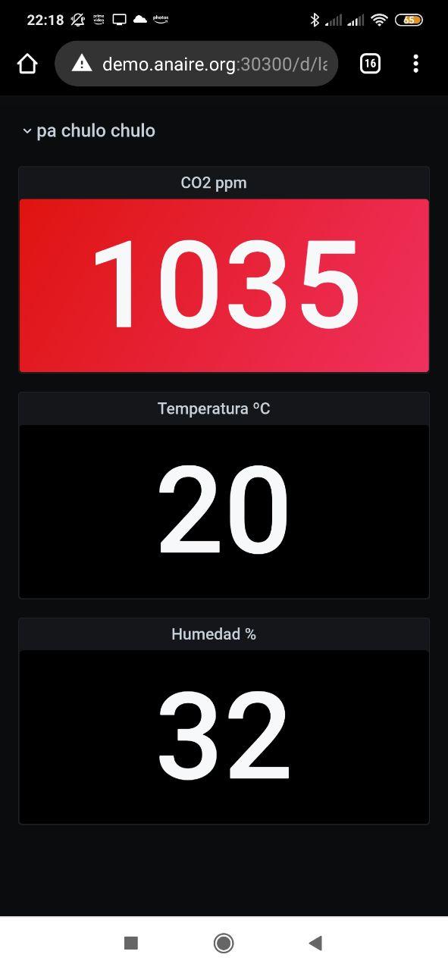
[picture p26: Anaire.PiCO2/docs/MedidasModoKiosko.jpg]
      
    </p>  

* Valores actuales con acceso a histórico. Pulsando en el botón de *Detalle* podrá visualizar la evolución temporal de las medidas.
    https://portal.anaire.org/admin/ID_del_dispositivo/

    <p align="center">
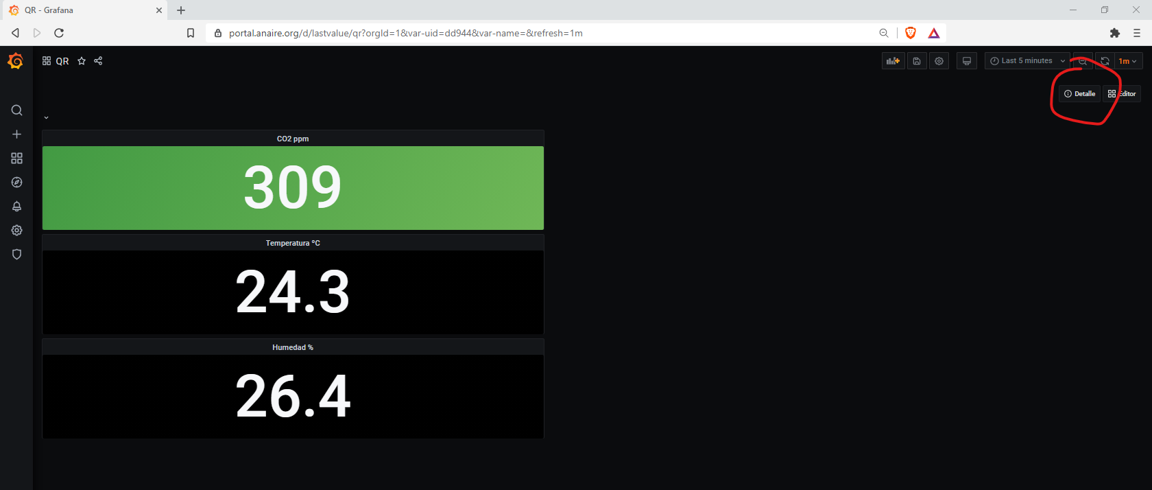
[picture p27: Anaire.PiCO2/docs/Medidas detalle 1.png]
      
    </p>

    <p align="center">
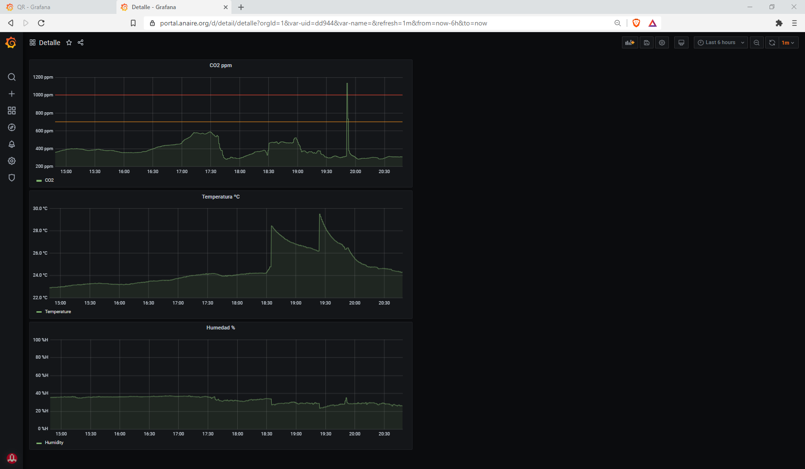
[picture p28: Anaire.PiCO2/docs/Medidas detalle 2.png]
      
    </p>

Si desea gestionar un conjunto de dispositivos PiCO2 o Anaire 30/50ppm para una organización, envíe los ID de sus dispositivos al correo anaire@anaire.org para que le configuremos cuadros de control automáticos como los siguientes, sin coste alguno:

Panel general con la visión instantánea:
<p align="center">
  
</p>

Panel de evolución temporal:
<p align="center">
  
</p>

También podemos configurar alarmas por correo electrónico, por Telegram, etc. Póngase en contacto con nosotros si tiene necesidades de gestión de un conjunto de dispositivos para que podamos ayudarle a diseñar una solución a medida de su organización.

# 6. Diagnóstico

Conecte el dispositivo al PC utilizando un cable USB-C. Arranque el monitor serie del IDE de Arduino con la opción *Herramientas -> Monitor serie*. Se abrirá una nueva ventana en la que se imprimirán todos los mensajes emitidos por el dispositivo durante su funcionamiento, que ayudarán a diagnosticar los posibles problemas. Se recomienda reiniciar el dispositivo pulsando dos veces el botón inferior para forzar el reinicio y poder observar un ciclo completo de funcionamiento desde el inicio del dispositivo.

Inicialmente el dispositivo mostrará la medida de 0 PPM. Si esta medición no cambia antes de un minuto desde que el dispositivo esté encendido, el sensor de CO2 no está siendo detectado por la tarjeta de control TTGO T-Display. Si esto sucede se recomienda conectar el dispositivo al ordenador y observar las trazas enviadas por el medidor tal como se describe en el punto anterior, para verificar el estado del dispositivo.

En el lateral izquierdo de la pantalla del PiCO2 se muestran 3 iconos: un indicador de conexión a la red Wifi, un altavoz que indica el estado de la alarma acústica, y un indicador de la carga de la batería. Cuando no hay conexión a la red el icono correspondiente aparecerá tachado. Cuando se configure la conexión WiFi o se vuelva a tener cobertura en caso de haberla perdido, el icono dejará de estar tachado, indicando que se ha recuperado la conectividad. De forma análoga, el icono del altavoz mostrará el estado de la alarma acústica, y el icono de la pila mostrará el nivel de carga de la batería.

---

# BONUS

## Montaje sobre Breadboard (placa de prototipado)
El montaje sobre breadboard es algo que puede ser útil para proyectos educativos, o para desarrollo, o incluso en caso de no tener acceso a una impresora 3D.

Es extremadamente sencillo montar el PiCO2 sobre breadboard. El siguiente vídeo muestra el proceso en detalle para el Anaire 30ppm. Realice el mismo procedimiento, pero sustituyendo la tarjeta NodeMCU por la tarjeta TTGO T-Display, dejando de lado el display que se muestra en el vídeo (no es necesario ya que la TTGO incorpora su propia pantalla) y cargando el *software* como se ha indicado en el apartado de fabricación del PiCO2:

Montaje Anaire30ppm breadboard (https://youtu.be/d87cvSwYpxk)

En este caso es relevante destacar que tras soldar los cuatro pines en el SCD30, utilizando éstos se puede pinchar el sensor directamente en la placa de prototipado, alineado correctamente con los pines de la tarjeta TTGP T-Display para que se verifique el cableado deseado, ahorrando así cuatro cables y facilitando el engarce mecánico del conjunto de una forma sencilla y muy efectiva.

Este montaje es muy sencillo de realizar, pero hay que tener en cuenta que la proximidad entre el sensor SCD30 y el microcontrolador en la placa TTGO T-Display puede producir que haya alteración de las medidas realizadas, especialmente las de temperatura y humedad. Adicionalmente, el sensor queda expuesto a corrientes de aire o fuentes de luz que producen alteraciones significativas de las medidas. Siempre resulta conveniente poder alojar mecánicamente el conjunto en algún tipo de caja protectora.

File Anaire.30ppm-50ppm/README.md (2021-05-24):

# Anaire 30/50ppm

*@2021 Anaire www.anaire.org*

---
<p align="center">
  
</p>  

# Tabla de contenidos
[1. Hardware](#id1)  
[2. Software](#id2)  
[3. Fabricación](#id3)  
[4. Configuración](#id4)  
[5. Uso](#id5)  
[6. Diagnóstico](#id6)  

---

# 1. Hardware
El medidor Anaire es un dispositivo basado en un microcontrolador ESP8266 dispuesto en una tarjeta de control [AZ Delivery NodeMCU LUA Amica V2](https://www.az-delivery.de/es/products/nodemcu?_pos=3&_sid=fd8b40ecd&_ss=r), que proporciona también conectividad WiFi, y permite su programación desde el IDE de Arduino. Para realizar las medidas se conectan sensores de CO2, temperatura y humedad. Adicionalmente se conectan un display para mostrar las mediciones e indicaciones de estado, y un zumbador para poder emitir alertas sonoras.

Con objeto de simplificar la fabricación y no añadir más componentes aun proporcionando máxima funcionalidad, se utilizan los siguientes elementos ya disponibles en la tarjeta NodeMCU:

<p align="center">
  
</p>

* Se emplea uno de los dos LED incorporados a la tarjeta NodeMCU, el más próximo al conector Micro USB, para proporcionar alertas visuales sobre el estado de CO2. El LED está encendido en estado normal, es decir, cuando el valor medido del CO2 está por debajo del umbral de aviso; parpadea lentamente cuando el dispositivo está en estado de aviso por CO2, y parpadea rápidamente en caso de encontrarse en alarma. Las frecuencias de parpadeo son iguales a las de la alerta sonora proporcionada por el zumbador.

* Se emplea el botón de Flash (a la derecha del conector Micro USB) poder deshabilitar la alerta local. Y para volverla a habilitar, ya que el botón conmuta entre ambos estados.
  * Adicionalmente, cada vez que se presiona el botón de Flash se muestran el modelo, el ID y la dirección IP del dispositivo, hasta la realización de la siguiente medición.

* Presionando dos veces consecutivas el botón de Reset (a la izquierda del conector MicroUSB) el dispositivo se reinicia en modo de portal cautivo, lo que permite la configuración de la red WiFi y el acceso a otros parámetros de configuración, como se explica en el apartado de Configuración, más adelante.

El dispositivo es plenamente operativo incluso sin el display y sin el zumbador. Para funcionar con mínimo coste y complejidad sólo es necesaria una tarjeta de control NodeMCU y un sensor de CO2. Todos los demás elementos son opcionales.

Para los sensores de CO2 existen dos alternativas. Actualmente se soportan dos sensores de CO2, ambos con tecnología NDIR: el [*Sensirion SCD30*](https://www.sensirion.com/en/environmental-sensors/carbon-dioxide-sensors/carbon-dioxide-sensors-scd30/) y el [*Winsen MHZ14A*](https://www.winsen-sensor.com/sensors/co2-sensor/mh-z14a.html).

El Sensirion SCD30 es un sensor de mayor calidad: tiene mayor precisión (30 ppm frente a los 50 ppm del MH-Z14A); incorpora sensor de temperatura y humedad, con lo que no hay que añadir un sensor adicional para medir temperatura y humedad, facilitando la fabricación, además de permitir mecanismos de compensación por altitud y temperatura; tiene un mecanismo de autocalibración más robusto, en el que se hace uso de las mediciones de los últimos 30 días, en lugar de las últimas 24 horas, como en el caso del MH-Z14A; su respuesta es también más rápida ante cambios atmosféricos (por ejemplo, al introducir ventilación en un espacio cerrado). Los inconvenientes del Sensirion SCD30 son que es más caro, que es más frágil para su manipulación y que tiene menos opciones de compra y normalmente mayores plazos de entrega. El MH-Z14A está disponible en todo tipo de plataformas de comercio electrónico. Para comprar el Sensirion SCD30 hay que recurrir normalmente a plataformas más especializadas en componentes electrónicos.

El software del medidor Anaire 30/50ppm es compatible con ambos sensores, y detecta automáticamente cuál de los dos está en uso, adaptándose a ello sin necesidad de realizar ningún cambio de configuración.

En caso de utilizar el sensor MH-Z14A como medidor de CO2 se ha incorporado adicionalmente el sensor [AZ Delivery DHT11](https://www.az-delivery.de/es/products/dht11-temperatursensor-modul) como sensor de temperatura y humedad. Si se está utilizando el sensor SCD30 no es necesario incorporar ningún componente adicional, ya que éste incorpora sensor de temperatura y humedad, además de realizar la medida del CO2. En cualquier caso se recomienda encarecidamente el análisis de la documentación técnica de ambos sensores, especialmente para la interpretación de las medidas y la determinación de procedimientos de recalibración, en caso de considerarlo necesario para optimizar la evolución de la precisión de las medidas con el paso del tiempo y en función de la utilización del dipositivo (ubicación, régimen de ventilación, etc.)

La alimentación del dispositivo se realiza directamente a través del puerto Micro USB de la tarjeta de control [NodeMCU LUA Amica V2](https://www.az-delivery.de/es/products/nodemcu?_pos=3&_sid=fd8b40ecd&_ss=r), el mismo que se utiliza para programarla y para comunicarse con ella. Se recomienda utilizar fuentes de alimentación (enchufes USB, puertos USB en ordenadores, etc.) que puedan proporcionar al menos 1.000 mA (que es lo más frecuente, aunque podría no ser así en el caso de antiguos cargadores de teléfonos móviles, por ejemplo).   

A continuación se enumeran los elementos citados, incluyendo enlaces a su documentación.

## 1.1 Elementos comunes
* Tarjeta de control basada en microcontrolador ESP8266:  [AZDelivery NodeMCU LUA Amica V2](https://www.az-delivery.de/es/products/nodemcu?_pos=3&_sid=fd8b40ecd&_ss=r)  

<p align="center">
    
</p>

* Display OLED: [AZDelivery 0.91 inch OLED I2C Display 128 x 32 Pixels](https://www.az-delivery.de/es/products/0-91-zoll-i2c-oled-display?_pos=2&_sid=8c7ab3c5f&_ss=r)  

<p align="center">
    
</p>

* Zumbador: [AZDelivery Active Buzzer](https://www.az-delivery.de/es/products/buzzer-modul-aktiv?_pos=2)  

<p align="center">
    
</p>

* Caja [AnaireBox](https://www.thingiverse.com/thing:4694633) para impresora 3D  

<p align="center">
  
</p>    
<p align="center">
  
</p>  

* [Cables Dupont hembra-hembra de 10cm de longitud](https://es.aliexpress.com/item/32223527499.html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)

<p align="center">
  
</p>

* Será necesario un cable válido para conectar desde un puerto USB del ordenador al puerto Micro USB de la tarjeta NodeMCU, para poder cargar el software del dispositivo. Este mismo cable puede ser utilizado para la alimentación eléctrica desde un ordenador, o desde un enchufe USB o incluso desde una batería portátil USB. También podría utilizarse, una vez cargado el software, un transformador de un antiguo teléfono móvil u otro tipo de dispositivo que tenga un conector Micro USB y proporcione al menos 1.000 miliamperios. Por ejemplo, [este cable](https://www.amazon.es/TM-Electron-CXU201020-Cable-Blanco/dp/B07BQD6P74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), o [este alimentador](https://www.amazon.es/gp/product/B00U88KSHO/ref=ppx_yo_dt_b_asin_title_o01_s00?ie=UTF8&psc=1)

## 1.2 Sensores
* Anaire30ppm: [*Sensirion SCD30*](https://www.sensirion.com/en/environmental-sensors/carbon-dioxide-sensors/carbon-dioxide-sensors-scd30/)
<p align="center">
  
</p>  

* Anaire50ppm: [*Winsen MHZ14A*](https://www.winsen-sensor.com/sensors/co2-sensor/mh-z14a.html)  
<p align="center">
  
</p>

* Adicionalmente, el medidor Anaire50ppm necesita el sensor de temperatura y humedad [AZ Delivery DHT11](https://www.az-delivery.de/es/products/dht11-temperatursensor-modul)  
  <p align="center">
    
  </p>  

* Para la conexión de cualquiera de los dos sensores de CO2 es preciso conectar 4 pines y soldarlos en las posiciones indicadas en el proceso de fabricación. Se pueden comprar pines como [éstos](https://www.amazon.es/Pin-Header-Way-Straight-Pitch/dp/B00QXBRCKG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), por ejemplo, y cortar trozos de 4 pines con un alicate de corte o unas tijeras.

# 2. Software

El dispositivo se programa exactamente igual que una tarjeta arduino, utilizando el [entorno de desarrollo de Arduino](https://www.arduino.cc/en/software).

Adicionalmente hay que instalar algunos componentes de software en el entorno de Arduino, principalmente diversas librerías. La descripción completa de la instalación del entorno de *software* se puede encontrar al inicio del archivo de código fuente del dispositivo medidor [NodeMCULuaAmicaV2.ino](https://github.com/anaireorg/anaire-devices/blob/main/Anaire.30ppm-50ppm/anaire-device.NodeMCULuaAmicaV2/anaire-device.NodeMCULuaAmicaV2.ino).

En cualquier caso la instalación del entorno completo de desarrollo no será necesaria si no se requiere hacer modificaciones en el software. Para la fabricación del dispositivo se proporciona un mecanismo sencillo basado en la carga del [binario ya compilado](https://github.com/anaireorg/anaire-devices/blob/main/Anaire.30ppm-50ppm/anaire-device.NodeMCULuaAmicaV2/anaire-device.NodeMCULuaAmicaV2.ino.nodemcu.bin) en la tarjeta NodeMCU, como se describe más adelante, en el apartado de fabricación.

Para cualquiera de las dos opciones será necesario instalar previamente en un ordenador con sistema operativo Windows10 el [driver USB-UART](https://www.silabs.com/developers/usb-to-uart-bridge-vcp-drivers) (conversión USB a puerto serie) para poder comunicarse con la tarjeta TTGO T-Display.

A continuación se describe en detalle el procedimiento para poder preparar un entorno de desarrollo de SW operativo que permita la carga del software en los dispositivos y su programación para modificarlo, en caso deseado. En este vídeo se puede seguir todo el proceso paso a paso tanto para la preparación del entorno como para la carga del sotware.

Preparación del entorno y carga del software para Anaire30ppm y Anaire50ppm (https://youtu.be/nSNwYwKNmuk)

# 3. Fabricación

Se han diseñado dos modelos de medidores basados en el *hardware* descrito: **Anaire30ppm**, con precisión de 30 ppm (sensor Sensirion SCD30) y **Anaire50ppm**, con precisión de 50 ppm (sensores Winsen MHZ14A y AZ Delivery DHT11). Ambos se pueden fabricar mediante la misma caja [AnaireBox](https://www.thingiverse.com/thing:4694633), utilizando una impresora 3D, para montar mecánicamente los componentes. La caja puede acoger cualquiera de las dos combinaciones de sensores anteriores ya que está diseñada para ser compatible con ambos.  para impresora 3D

Las opciones de montaje que se proponen pretenden simplificar al máximo el proceso, manteniendo las máximas prestaciones técnicas. En cualquier caso se proporciona toda la información necesaria para que cualquiera pueda plantearse alternativas de fabricación, por ejemplo, mediante placas PCB y soldadura de los componentes. Para ello se publican en este mismo repositorio los archivos necesarios en formato de la aplicación [Fritzing](https://fritzing.org/) con la información detallada del cableado requerido, que pueden servir de punto de partida para el diseño de la placa PCB.  

  * [Archivo Fritzing para Anaire30ppm (Sensirion SCD-30)](https://github.com/anaireorg/anaire-devices/blob/main/Anaire.30ppm-50ppm/docs/Anaire30ppm_SCD30.fzz)

  * [Archivo Fritzing para Anaire50ppm (Winsen MH-Z14A)](https://github.com/anaireorg/anaire-devices/blob/main/Anaire.30ppm-50ppm/docs/Anaire50ppm_MHZ14A.fzz)

## 3.1 Anaire30ppm

### Esquema de conexiones  
<p align="center">
  
</p>  

### Detalle del sensor SCD30  
Hay que soldar 4 pines como se muestra en la siguiente imagen  
<p align="center">
  
</p>  

### Montaje final  

El siguiente vídeo muestra de forma detallada el montaje completo del medidor Anaire 30ppm:

Montaje Anaire30ppm box (https://youtu.be/VRJ4Hir3wzU)

<p align="center">
  
</p>  

<p align="center">
  
</p>  

## 3.2 Anaire50ppm

### Esquema de conexiones  
<p align="center">
  
</p>  

### Detalle del sensor MH-Z14A  
Hay que soldar 4 pines como se muestra en la siguiente imagen  
<p align="center">
  
</p>  

### Montaje final  
El siguiente vídeo muestra el montaje completo del medidor Anaire 50ppm en detalle:

Montaje de Anaire50ppm Box (https://youtu.be/fMnoskmz7p4)

Imágenes del montaje:
<p align="center">
  
</p>  

<p align="center">
  
</p>  

## 3.3 Carga del software
Una vez completado el montaje de los componentes, hay que proceder a la carga del software en la tarjeta de control NodeMCU. El software es el mismo, independientemente del modelo de medidor que se haya fabricado.

Para la carga del software hay dos opciones: carga del binario compilado, o carga del código fuente desde el IDE de Arduino. Como ya se ha explicado anteriormente, si no se desea modificar el software se recomienda la primera opción, ya que es mucho más sencilla y rápida.

En cualquiera de los dos casos es preciso instalar previamente en un ordenador con sistema operativo Windows 10 el [driver USB-UART](https://www.silabs.com/developers/usb-to-uart-bridge-vcp-drivers) (conversión USB a puerto serie) para poder comunicarse con la tarjeta TTGO T-Display.

### Carga del binario compilado
Estas instrucciones son únicamente válidas para ordenadores con el sistema operativo Windows 10.

Asegure que se tiene en un directorio los siguientes archivos y carpetas, disponibles en la carpeta [anaire-device.NodeMCULuaAmicaV2](https://github.com/anaireorg/anaire-devices/tree/main/Anaire.30ppm-50ppm/anaire-device.NodeMCULuaAmicaV2):

Archivos:
  * flash_device.bat
  * anaire-device.NodeMCULuaAmicaV2.ino.nodemcu.bin
Carpeta:
  * flash_device_tools

Ejecute los siguientes pasos en esa carpeta:

1. Conecte el medidor Anaire 30/50ppm al ordenador mediante un cable MicroUSB. En el administrador de dispositivos de windows podrá identificar el puerto COM asignado por el sistema operativo al medidor Anaire 30/50ppm.

<p align="center">
  
</p>

2. Haga click derecho en el archivo [flash_device.bat](https://github.com/anaireorg/anaire-devices/blob/main/Anaire.30ppm-50ppm/anaire-device.NodeMCULuaAmicaV2/flash_device.bat) y seleccione la opción de *editar*

3. Donde pone *--port COMXX* sustituya el puerto COMXX para poner el que haya identificado previamente en el paso 1, seleccione *archivo->guardar* y cierre la ventana

<p align="center">
  
</p>

4. Haga doble click en el archivo [flash_device.bat](https://github.com/anaireorg/anaire-devices/blob/main/Anaire.30ppm-50ppm/anaire-device.NodeMCULuaAmicaV2/flash_device.bat). Al acabar la ejecución pedirá que se pulse cualquier tecla para cerrar la ventana. El medidor Anaire 30/50ppm arrancará con la última versión de *software* disponible en el archivo [anaire-device.NodeMCULuaAmicaV2.ino.nodemcu.bin](https://github.com/anaireorg/anaire-devices/blob/main/Anaire.30ppm-50ppm/anaire-device.NodeMCULuaAmicaV2/anaire-device.NodeMCULuaAmicaV2.ino.nodemcu.bin)

<p align="center">
  
</p>

### Carga desde el código fuente

1. Instale el [entorno de desarrollo de Arduino](https://www.arduino.cc/en/software).

2. Instale los componentes de software requeridos en el entorno de Arduino, tal como se describe al inicio del archivo de código fuente del dispositivo medidor [anaire-device.NodeMCULuaAmicaV2.ino](https://github.com/anaireorg/anaire-devices/blob/main/Anaire.30ppm-50ppm/anaire-device.NodeMCULuaAmicaV2/anaire-device.NodeMCULuaAmicaV2.ino).

3. Cargue el programa [anaire-device.NodeMCULuaAmicaV2.ino](https://github.com/anaireorg/anaire-devices/blob/main/Anaire.30ppm-50ppm/anaire-device.NodeMCULuaAmicaV2/anaire-device.NodeMCULuaAmicaV2.ino) en el IDE de Arduino utilizando la opción *Archivo->Abrir*

4. Conecte mediante un cable MicroUSB el Anaire 30/50ppm al ordenador

5. Seleccione el puerto apropiado en *Herramientas -> Puerto*. Si sólo tiene un Anaire 30/50ppm conectado, sólo debería aparecer una opción para seleccionar. Si no aparece ninguna, o bien no se ha instalado correctamente el [driver USB-UART](https://www.silabs.com/developers/usb-to-uart-bridge-vcp-drivers), o bien el cable MicroUSB o la tarjeta NodeMCU son defectuosos.

6. Presione el botón de carga, que se indica en el IDE con una flecha apuntando hacia la derecha, y espere a que se compile y se descargue el software en la tarjeta NodeMCU.

<p align="center">
  
</p>

El proceso puede durar varios minutos, dependiendo de la potencia de cálculo del ordenador. Al término del proceso en el IDE de Arduino se mostrará un mensaje indicando que se ha escrito el 100% del programa en la tarjeta, y el dispositivo PiCO2 se reiniciará mostrando durante varios segundos la imagen de Anaire en la pantalla, para a continuación comenzar a mostrar medidas cada 5 segundos.

En el siguiente vídeo puede verse el proceso completo al detalle:

Preparación del entorno y carga del software para Anaire30ppm y Anaire50ppm (https://youtu.be/nSNwYwKNmuk?t=260)

# 4. Configuración

El medidor tiene un identificador único (o ID) generado a partir de la dirección MAC de la interfaz WiFi de cada tarjeta NodeMCULuaAmicaV2. Este ID es un texto hexadecimal de 6 caracteres, utilizado para el acceso a las medidas en Internet y la integración del medidor en la aplicación en la nube de Anaire. No es preciso realizar ninguna configuración sobre este identificador, se realiza de forma automática.

El ID del dispositivo se muestra durante el inicio y tras pulsar el botón de Flash (en la caja AnaireBox es el botón superior, con la letra *A*).

Para completar la configuración del dispositivo Anaire 30/50ppm hay que conectarlo a una red WiFi y realizar la calibración de referencia.

## Configuración de la conexión WiFi

* Tras pulsar 2 veces consecutivas el botón de Reset (en la caja AnaireBox es el botón inferior, con la letra *R* o con la letra *B*), el dispositivo se reinicia en modo de configuración, creando una red WiFi y un portal cautivo para la configuración:
   * Se crea una red WiFi abierta con el nombre ESP_XXXXXX, donde XXXXXX es el identificador del dispositivo
   * Conecte a esa red con un PC, tablet o teléfono móvil
   * Una vez conectado a la red introduzca la siguiente dirección IP **192.168.4.1** en su navegador. De esta forma se accede al portal de configuración del dispositivo
   * En el portal puede escoger una red WiFi entre las detectadas, e introducir la contraseña de la red. Pulse en el botón *Save* tras escribir la contraseña.
     * Si todo ha ido correctamente el dispositivo se reiniciará con conexión a la nueva red WiFi
     * Si ha habido algún problema de conexión (por ejemplo, si se ha introducido una contraseña errónea), el dispositivo mostrará un mensaje de error WiFi en el display, y deberá repetir el procedimiento

## Calibración de referencia

Sitúe el medidor Anaire 30/50ppm al aire libre, protegido del sol, de otras fuentes de luz intensas y de las corrientes de aire (por ejemplo, dentro de una caja de cartón en el alféizar de la ventana), y arranque el proceso de calibración mediante alguno de los siguientes métodos:
 - Presione el botón superior, etiquetado con la letra "A" durante más de 10 segundos, hasta que la pantalla muestre una cuenta atrás indicando el número de segundos restantes hasta que se complete la calibración.
 - Identifique la dirección IP del dispositivo pulsando brevemente el botón superior, e introduzca la dirección en un navegador de un dispositivo conectado a la misma red WiFi. En el servidor web haga click en el enlace que permite iniciar la calibración de referencia del dispositivo.
 - Acceda a la aplicación en la nube, entrando en la opción de editor de parámetros. Para ello debe tener permisos de administrador en la aplicación. Active la opción denominada *Forced calibration* y haga click en el botón *Update*. de esta forma podrá iniciar la calibración a través de Internet.

 En cualquiera de los métodos anteriores la pantalla del Anaire 30/50ppm una cuenta atrás para indicar el tiempo restante para que se complete la calibración forzada. Este tiempo depende del sensor equipado, siendo de 1 minuto en el caso del Sensirion SCD30 y de 10 minutos en el caso del Winsen MHZ-14A. No interfiera con el dispositivo, ni lo manipule o lo acerque a fuentes de CO2 (como la respiración) mientras dure la cuenta atrás.

 Al término del proceso el dispositivo se reiniciará y volverá a tomar medidas, tomando como referencia el valor de 400 ppm (este valor se puede modificar desde la aplicación en la nube para el sensor scd30). El proceso no puede ser interrumpido, deberá esperar a su término en cualquier caso, o retirar la alimentación del Anaire 30/50ppm si desea interrumpirlo.

# 5. Uso

Para empezar a realizar medidas sólo tiene que alimentar el Anaire 30/50ppm con un cable MicroUSB.
* Durante un segundo se muestra el texto *anaire.org* en el display
* A continuación el ID y la versión de *software* durante otro segundo
* A continuación se mostrarán tres líneas en el display, indicando el modelo de dispositivo (anaire 30ppm o 50ppm), el ID automáticamente asignado y un número con una cuenta atrás por segundos debida al precalentamiento del sensor de CO2: 3 segundos en el Anaire30ppm, 3 minutos en el Anaire50ppm. Los sensores de CO2 requieren de un tiempo de estabilización y calentamiento para su puesta en marcha de forma correcta.  
* Una vez concluida la cuenta atrás el dispositivo mostrará las medidas de CO2, temperatura y humedad.

En caso de que el valor medido de CO2 supere el umbral de aviso, el dispositivo empezará a emitir un pitido intermitente, así como el parpadeo del LED de estado de CO2 y del valor en el display.Los valores por defecto de los umbrales son 700 PPM para el aviso y 1.000 PPM para la alarma. Estos valores se pueden modificar desde la aplicación de Anaire en la nube.

Si se desea detener la indicación local de alarma (visual y sonora), presione una vez el botón "A" ("flash" en la propia placa). El display mostrará, de forma adicional, el modelo, el ID y la dirección IP del dispositivo. Si se vuelve a presional el botón de Flash, se reactivará el aviso de alarma local. Es decir, el botón de Flash permite conmutar entre avisar o no de forma local cuando los valores de CO2 superen los umbrales establecidos.

Cuando la medida de CO2 sea inferior al umbral de aviso, el dispositivo reseteará el estado de la señal local de alarma, de forma que automáticamente volverá a dar indicaciones locales de alarma si se vuelven a superar los umbrales de aviso o de alarma en el futuro, sin necesidad de reactivar la alarma local.

Si hay algún error, la última línea del display mostrará el error. El dispositivo está diseñado para recuperarse automáticamente de los errores cuando la causa que los provoca se ha resuelto, sin que el usuario tenga que intervenir.

##  Botones
El Anaire 30/50ppm tiene dos botones en la parte inferior derecha, el superior, etiquetado con la letra "A", y el inferior, etiquetado con la letra "R". Puede usar los botones para realizar las siguientes funciones:

### Botón superior "A"
- Pulsación corta - Conmuta el estado de la alarma acústica y muestra información del dispositivo: ID,  dirección IP y versión de *software*
- Pulsación larga durante más de 10 segundos - Inicia el proceso de calibración forzada.

### Botón inferior "R"
- Pulsación corta - Reinicia el Anaire 30/50ppm
- Doble pulsación en menos de 10 segundos - Arranca el portal cautivo que permite configurar la conexión WiFi y la dirección del servidor MQTT de la aplicación Anaire en la nube a la que enviar las medidas

## Servidor Web
Si se conecta con un dispositivo a la misma red WiFi a la que esta conectado el medidor PiCO2, accediendo a la dirección IP del medidor mediante un navegador se puede acceder al servidor web del Anaire 30/50ppm, pudiendo así acceder a información detallada del dispositivo, a las últimas medidas, e incluso pudiendo realizar diversas acciones de configuración, como se puede ver en la siguiente imagen:

<p align="center">
  
</p>

## Acceso por internet a las medidas:
Si se ha conectado el Anaire 30/50ppm a una red WiFi con acceso a internet y se han dejado los valores por defecto de conexión a la aplicación en la nube, se puede acceder a los valores medidos por el dispositivo en los siguientes enlaces. Sustituya *ID_del_dispositivo* por el ID del PiCO2 en cuestión para acceder a las medidas:

* Valores actuales en modo kiosko (modo muy práctico para visualizar las medidas en un teléfono móvil por ejemplo):  
    https://portal.anaire.org/sensor/ID_del_dispositivo/

    <p align="center">
      
    </p>  

* Valores actuales con acceso a histórico. Pulsando en el botón de *Detalle* podrá visualizar la evolución temporal de las medidas.
    https://portal.anaire.org/admin/ID_del_dispositivo/

    <p align="center">
      
    </p>

    <p align="center">
      
    </p>

Si desea gestionar un conjunto de dispositivos PiCO2 o Anaire 30/50ppm para una organización, envíe los ID de sus dispositivos al correo anaire@anaire.org para que le configuremos cuadros de control automáticos como los siguientes, sin coste alguno:

Panel general con la visión instantánea:
<p align="center">
  
</p>

Panel de evolución temporal:
<p align="center">
  
</p>

También podemos configurar alarmas por correo electrónico, por Telegram, etc. Póngase en contacto con nosotros si tiene necesidades de gestión de un conjunto de dispositivos para que podamos ayudarle a diseñar una solución a medida de su organización.

# 6. Diagnóstico

Conecte el dispositivo al PC utilizando un cable USB. Arranque el monitor serie del IDE de Arduino con la opción *Herramientas -> Monitor serie*. Se abrirá una nueva ventana en la que se imprimirán todos los mensajes emitidos por el dispositivo durante su funcionamiento, que ayudarán a diagnosticar los posibles problemas. Se recomienda presionar una vez el botón de *Reset* para reiniciar el dispositivo y poder observar un ciclo completo de funcionamiento desde el principio.

Los siguientes errores se pueden mostrar en el display del medidor. Se indica su significado y cómo proceder para cada uno de ellos:

* err_wifi: no se pudo conectar a la red WiFi. Compruebe el estado de la conexión presionando dos veces consecutivas el botón de *Reset* y conectando al portal cautivo, como se explica en el apartado de Configuración del dispositivo.
* err_mqtt: no se pudo conectar al servidor MQTT de la aplicación de Anaire en la nube. Compruebe los detalles al inicio del código del dispositivo y verifique la conectividad del servidor definido.
* err_co2: no se pudo conectar con el sensor de CO2. Compruebe las conexiones.
* err_dht: no se pudo conectar con el sensor de humedad y temperatura DHT11. Compruebe las conexiones.

---

# BONUS

## Montaje sobre Breadboard

El montaje sobre breadboard es algo que puede ser útil para proyectos educativos, o para desarrollo, o incluso en caso de no tener acceso a una impresora 3D.

***Anaire 30ppm***

Es extremadamente sencillo montar el Anaire30ppm sobre breadboard. El siguiente vídeo muestra el proceso en detalle:

Montaje Anaire30ppm breadboard (https://youtu.be/d87cvSwYpxk)

En este caso es relevante destacar que tras soldar los cuatro pines en el SCD30, utilizando éstos se puede pinchar el sensor directamente en la placa de prototipado, alineado correctamente con los pines de la NodeMCU para que se verifique el cableado deseado, ahorrando así cuatro cables y facilitando el engarce mecánico del conjunto de una forma sencilla y muy efectiva.

<p align="center">
  
</p>  

Este montaje es muy sencillo de realizar, pero hay que tener en cuenta que la proximidad entre el sensor SCD30 y el microcontrolador en la placa NodeMCU puede producir que haya alteración de las medidas realizadas, especialmente las de temperatura y humedad. Adicionalmente, el sensor queda expuesto a corrientes de aire o fuentes de luz que producen alteraciones significativas de las medidas. Siempre resulta conveniento poder fijar mecánicamente el conjunto en algún tipo de caja protectora.

***Anaire 50ppm***

El siguiente vídeo muestra de forma detallada el montaje completo con el sensor MHZ-14A sobre breadboard:

Montaje de Anaire50ppm Breadboard (https://youtu.be/tY8MLtDSswg)

<p align="center">
  
</p>  

De nuevo es deseable introducir en montaje en una caja que pueda proteger el prototipo de corrientes de aire o la exposición directa a fuentes intensas de luz, de forma que las medidas sean más estables.

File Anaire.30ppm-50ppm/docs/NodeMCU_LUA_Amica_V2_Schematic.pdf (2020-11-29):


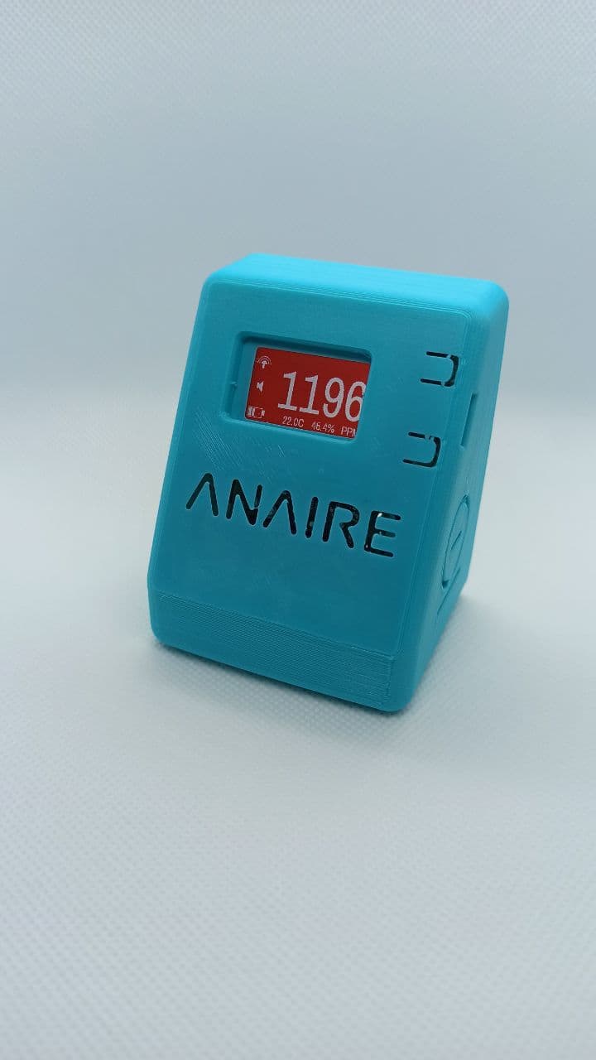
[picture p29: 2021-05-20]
Anaire.PiCO2/docs/PiCO2 Frontal Alarma.jpg

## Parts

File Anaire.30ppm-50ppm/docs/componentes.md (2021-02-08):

# Lista en AliExpress
El medidor Anaire50ppm puede construirse por sólo 20€ si se compran los componentes en Aliexpress. El inconveniente es que habrá que esperar varios días a que los componentes lleguen desde China. Cuidado: algunos productos pueden tener múltiples opciones al realizar la compra.  

## Anaire50ppm en AliExpress:
 - [Sensor CO2 MH-Z14A](https://es.aliexpress.com/item/32663184156.html?spm=a2g0s.9042311.0.0.274263c0jDdpWO)
 - [Sensor temperatura/humedad DHT11](https://es.aliexpress.com/item/32822426717.html?spm=a2g0s.9042311.0.0.274263c0jDdpWO)
 - [Zumbador](https://es.aliexpress.com/item/32740530954.html?spm=a2g0s.9042311.0.0.5dcd63c0hebK0V)
 - [Display](https://es.aliexpress.com/item/32672229793.html?spm=a2g0s.9042311.0.0.5dcd63c0hebK0V)
 - [ESP8266 ESP-12F NodeMCU Amica V2](https://es.aliexpress.com/item/32665100123.html?spm=a2g0s.9042311.0.0.5dcd63c0hebK0V)
 - [Cables Dupont](https://es.aliexpress.com/item/32854553966.html?spm=a2g0s.9042311.0.0.274263c0SKVuuY)

## Anaire30ppm en AliExpress:
 - El sensor de CO2 SCD30 no está disponible en Aliexpress. Se puede comprar en una de estas opciones. El precio en función del número de sensores puede cambiar con el tiempo, así que conviene revisar ambas opciones:
   - [Sensor CO2 SCD30 en Digikey](https://www.digikey.es/product-detail/es/sensirion-ag/SCD30/1649-1098-ND/8445334)
   - [Sensor CO2 SCD30 en Mouser](https://www.mouser.es/ProductDetail/Sensirion/SCD30?qs=rrS6PyfT74fdywu4FxpYjQ%3D%3D)
 - [Zumbador](https://es.aliexpress.com/item/32740530954.html?spm=a2g0s.9042311.0.0.5dcd63c0hebK0V)
 - [Display](https://es.aliexpress.com/item/32672229793.html?spm=a2g0s.9042311.0.0.5dcd63c0hebK0V)
 - [ESP8266 ESP-12F NodeMCU Amica V2](https://es.aliexpress.com/item/32665100123.html?spm=a2g0s.9042311.0.0.5dcd63c0hebK0V)
 - [Cables Dupont](https://es.aliexpress.com/item/32854553966.html?spm=a2g0s.9042311.0.0.274263c0SKVuuY)

# Lista en Amazon
Comprar los componentes en Amazon encarece el dispositivo, pero se pueden tener los componentes mucho más rápido.

## Anaire50ppm en Amazon:
 - [Sensor CO2 MH-Z14A](https://www.amazon.es/dp/B07Z21Z158/?coliid=I80SE6DAOWEOF&colid=8NAKLGML187W&psc=1&ref_=lv_cv_lig_dp_it)
 - [Sensor temperatura/humedad DHT11](https://www.amazon.es/dp/B089W8DB5P/?coliid=I7JQ2GPD1SWKM&colid=8NAKLGML187W&psc=1&ref_=lv_cv_lig_dp_it)
 - [Zumbador](https://www.amazon.es/dp/B089QJKJXW/?coliid=I3JWYXIKQYD5OU&colid=8NAKLGML187W&psc=1&ref_=lv_cv_lig_dp_it)
 - [Display](https://www.amazon.es/dp/B079H2C7WH/?coliid=I16REZ6PQ0FBT3&colid=8NAKLGML187W&psc=1&ref_=lv_cv_lig_dp_it)
 - [ESP8266 ESP-12F NodeMCU Amica V2](https://www.amazon.es/dp/B06Y1LZLLY/?coliid=I2HJZZF8UFI7P3&colid=8NAKLGML187W&psc=1&ref_=lv_cv_lig_dp_it)
 - [Cables Dupont](https://www.amazon.es/gp/product/B07D5XF44S/ref=ppx_yo_dt_b_search_asin_title?ie=UTF8&psc=1)

## Anaire30ppm en Amazon:
 - El sensor de CO2 SCD30 no está disponible en Aliexpress. Se puede comprar en una de estas opciones. El precio en función del número de sensores puede cambiar con el tiempo, así que conviene revisar ambas opciones:
   - [Sensor CO2 SCD30 en Digikey](https://www.digikey.es/product-detail/es/sensirion-ag/SCD30/1649-1098-ND/8445334)
   - [Sensor CO2 SCD30 en Mouser](https://www.mouser.es/ProductDetail/Sensirion/SCD30?qs=rrS6PyfT74fdywu4FxpYjQ%3D%3D)
 - [Zumbador](https://www.amazon.es/dp/B089QJKJXW/?coliid=I3JWYXIKQYD5OU&colid=8NAKLGML187W&psc=1&ref_=lv_cv_lig_dp_it)
 - [Display](https://www.amazon.es/dp/B079H2C7WH/?coliid=I16REZ6PQ0FBT3&colid=8NAKLGML187W&psc=1&ref_=lv_cv_lig_dp_it)
 - [ESP8266 ESP-12F NodeMCU Amica V2](https://www.amazon.es/dp/B06Y1LZLLY/?coliid=I2HJZZF8UFI7P3&colid=8NAKLGML187W&psc=1&ref_=lv_cv_lig_dp_it)
 - [Cables Dupont](https://www.amazon.es/gp/product/B07D5XF44S/ref=ppx_yo_dt_b_search_asin_title?ie=UTF8&psc=1)

**Recomendación general:** Independientemente de si se compra a AliExpress o a Amazon, algún componente puede ser defectuoso. Es mejor, por tanto, comprar más unidades de las que realmente se necesitan, especialmente en el caso de AliExpress, pues el reemplazo tardaría más en llegar. Los sensores de CO2, que son la pieza más cara, son bastante fiables, así que no es tan necesario comprar unidades de más.

**Es necesario un cargador Micro-USB para alimentar el medidor.** En las listas no se ha incluido un cargador micro-usb necesario para alimentar a los dispositivos ya que es bastante normal disponer de este tipo de cargadores. Hay muchas opciones, como por ejemplo https://www.amazon.es/gp/product/B00U88KSHO/ref=ppx_yo_dt_b_asin_title_o07_s00?ie=UTF8&psc=1
En cualquier caso cualquier cargador Micro-USB de 5V y que proporcione al menos 1A debe valer sin problemas.

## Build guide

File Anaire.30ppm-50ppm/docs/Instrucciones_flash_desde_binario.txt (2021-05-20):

Para copiar el binario al medidor es necesario seguir los siguientes pasos:

Tener en el directorio los siguientes archivos/directorios:
* anaire-device.NodeMCULuaAmicaV2.ino.nodemcu.bin
* flash_device_tools
* flash_device.bat

Hacer click derecho en flash_device.bat, editar el puerto COM en el que tenemos conectado el dispositivo y guardar

Doble click el archivo flash_device.bat. Al acabar la ejecución pedirá que se pulse cualquier tecla para cerrar la ventana.

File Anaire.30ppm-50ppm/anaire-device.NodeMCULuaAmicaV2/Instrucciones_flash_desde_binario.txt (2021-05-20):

Para descargar el binario ya compilado al medidor Anaire 30/50ppm es necesario seguir los siguientes pasos:

Preparar un directorio con los siguientes archivos:
* flash_device.bat
* anaire-device.NodeMCULuaAmicaV2.ino.nodemcu.bin
Y también el siguiente directorio:
* flash_device_tools

Haga click derecho en el archivo flash_device.bat, y edite el puerto COM en el que está conectado el dispositivo. A continuación guarde el archivo y cierre la ventana.

Realice doble click el archivo flash_device.bat. Al acabar la ejecución pedirá que se pulse cualquier tecla para cerrar la ventana.

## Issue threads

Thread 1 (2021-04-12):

Posibilidad de guardar datos si no hay conección

rusosnith, 2021-04-12:
Pensando en escuelas que no tengan wifi o conectividad constante, se podrá pensar una opción en que guarde data (puede ser con mucha menos resolución que lo que hace cuando tiene wifi) y luego se descargue conectandose desde un celular via wifi como cuando se lo configura?

Esto necesitaría de un RTC clock aparte o podría tomar la hora de inicio?

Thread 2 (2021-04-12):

Agregar micrófono como sensor

rusosnith, 2021-04-12:
Pensando en monitorear aulas, especialmente de jardin de infantes, se podría pensar en agregar un sensor de volumen (tipo los lm386, muy baratos) para correlacionar cuando el aula esta en actividad o cuando está vacía, para poder ubicar más facil los momentos.

Se podría sumar opcional tanto como el HF11 y que suba los datos al panel igual que temperatura y humedad

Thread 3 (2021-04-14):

notificar si no esta conectado al wifi

rusosnith, 2021-04-14:
pensando en casos en que no se use siquiera el OLED, se podria usar el segundo led disponible para mostrar si esta o no conectado a wifi

seria un buen feature para usarlo en modo " solo logueo" sin oled ni alarmas visuales.

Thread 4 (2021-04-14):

posibilidad de configurarlo como "modo incógnito" *sin indicaciones en el led*

rusosnith, 2021-04-14:
De nuevo, pensando en el uso en aulas donde no se quiera interferir con la clase, se podría desactivar facil por código (un flag) esta opcion para que no moleste/llame la atencion el led

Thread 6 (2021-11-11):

SCD30 not working with esp32 board library v2.0.1

tanielkirikal, 2021-11-11:
Something has changed in esp32 board update from 1.0.6 to 2.0.1.
The i2c connection to SCD30 is not working anymore.
Maybe it is somehow connected with Wire library (it's updated  too as part of esp32 board package)

tanielkirikal, 2021-11-11:
Seedstudio library (I tried the examples) https://github.com/Seeed-Studio/Seeed_SCD30  work well with esp32 v 2.0.1
but Adafruit SCD30 library examples dont work. It looks now that Adafruit library is not compatible with new esp32 board software.

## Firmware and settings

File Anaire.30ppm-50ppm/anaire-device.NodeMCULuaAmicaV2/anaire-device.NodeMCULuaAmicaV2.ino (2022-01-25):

//////////////////////////////////////////////////////////////////////////////////////////////////////////////////////////////////////////////////////////////////////////////
// Anaire 30/50ppm - Open CO2, temperature and humidity measurement device connected to the Anaire Cloud Application https://github.com/anaireorg/anaire-cloud
// Init on 20201109 
// @anaire.org anaire@anaire.org
//////////////////////////////////////////////////////////////////////////////////////////////////////////////////////////////////////////////////////////////////////////////
//
// HW Parts - Common:
//   Control board: AZDelivery ESP8266 ESP-12F NodeMCU Lua Amica V2 https://www.az-delivery.de/es/products/nodemcu
//   Buzzer: AZDelivery Active Buzzer - https://www.az-delivery.de/es/products/buzzer-modul-aktiv?_pos=2&_sid=39cea0af6&_ss=r
//   Display: AZDelivery 0.91 inch OLED I2C Display 128 x 32 Pixels https://www.az-delivery.de/es/products/0-91-zoll-i2c-oled-display
//   3D printed Box designed by Anaire: https://www.thingiverse.com/thing:4694633
//
// HW Parts - Sensors:
//   Anaire 30ppm, better measurements precision: Sensirion SCD30 for CO2, temperature and humidity https://www.sensirion.com/en/environmental-sensors/carbon-dioxide-sensors/carbon-dioxide-sensors-scd30/
//   Anaire 50ppm, less cost: MHZ14A for CO2 https://www.winsen-sensor.com/sensors/co2-sensor/mh-z14a.html and AZ-Delivery DHT11 Temperature and humidity sensor - https://www.az-delivery.de/es/products/dht11-temperatursensor-modul
//
// SW Setup:
//   Install the usb to uart driver from https://www.silabs.com/developers/usb-to-uart-bridge-vcp-drivers
//   Start Arduino and open Preferences window.
//   Enter http://arduino.esp8266.com/stable/package_esp8266com_index.json into Additional Board Manager URLs field. You can add multiple URLs, separating them with commas.
//   Open Boards Manager from Tools > Board menu and find esp8266 platform by esp8266 community and install the software for Arduino from a drop-down box.
//   Select "NodeMCU 1.0" board from Tools > Board menu after installation
//
// Install the following libraries in Arduino IDE:
//   WiFiEsp by bportaluri https://github.com/bportaluri/WiFiEsp
//   Pubsubclient by Nick O'Leary https://pubsubclient.knolleary.net/
//   ArduinoJson by Benoit Blanchon https://arduinojson.org/?utm_source=meta&utm_medium=library.properties
//   esp8266-oled-ssd1306 by ThingPulse, Fabrice Weinberg https://github.com/ThingPulse/esp8266-oled-ssd1306
//   DHTesp by beegee_tokyo https://github.com/beegee-tokyo/DHTesp
//   ESP_EEPROM by j-watson https://github.com/jwrw/ESP_EEPROM
//   WifiManager by tzapu,tablatronix https://github.com/tzapu/WiFiManager
//   Double Reset detector by Stephen Denne https://github.com/datacute/DoubleResetDetector
//
//   MHZ-Z19 Library from WifWaf https://github.com/WifWaf/MH-Z19 Library - to manage Winsen CO2 sensors (tested with MHZ-14A and MHZ-19c) - INSTALL FROM ZIP FILE with Sketch-> Include Library-> Add .ZIP library
//   Modified paulvha SCD30 library, get it from anaire github on https://github.com/anaireorg/anaire-devices/blob/main/Anaire.30ppm-50ppm/docs/scd30-master.zip - INSTALL FROM ZIP FILE with Sketch-> Include Library-> Add .ZIP library
//
// Design:
// - The ID (last 3 fields from MAC address) and IP address are shown on OLED display during boot and after pressing the Flash button
// - Pressing the reset button ("R") twice in less than 10 seconds restarts the device in a captive web configuration portal, useful to configure local wifi settings and MQTT endpoint
// - All other local config parameters (like name, thresholds, local alarm, etc.) are configured via the cloud app, after connecting
// - Pressing Alarm button ("A") toggles between activating/deactivating local sound alarm alarms, and also show device information on the display
//   * Stops local sound alerting until pressed again
//   * It also shows device ID and IP address after being pressed during 3 seconds
// - Pressing Alarm button ("A") during more than 10 seconds activates forced calibration
// - Firmware update with latest fimrware available though cloud app
//   * Always using latest firmware on https://github.com/anaireorg/anaire-devices/blob/main/Anaire.30ppm-50ppm/anaire-device.NodeMCULuaAmicaV2/anaire-device.NodeMCULuaAmicaV2.ino.nodemcu.bin
// - Built in LED in GPIO16-D0 (the one that blinks near the nodemcu usb connector):
//   * When CO2 Status is "ok" (below warning threshold) LED and buzzer are off (normal status)
//   * When CO2 Status is "warning" builtin LED and external buzzer alternate blink at a slow pace (WARNING_BLINK_PERIOD)
//   * When CO2 Status is "alarm" builtin LED and external buzzer alternate blink at fast pace (ALARM_BLINK_PERIOD)
// - The device is designed to work only with the CO2 sensor, so buzzer, DHT11 humidity and temperature sensor, and OLED display are optional
// - The device is designed to recover from Wifi, MQTT or sensors reading temporal failures. Local measurements will always be shown in the local display.
// - The web server is activated, therefore entering the IP on a browser allows to see device specific details and measurements; device forced calibration is also available through the web server

//////////////////////////////////////////////////////////////////////////////////////////////////////////////////////////////////////////////////////////////////////////////////////////////////////////////////////
String sw_version = "v2.20220124.Ons";
// v2.20220124.Ons sound gets permanently deactivated when the button is pushed; changes in web server.
// v2.20210619.Naima homogeneizes treatment of MH-Z14A and MH-Z19c
// v2.2021520.Malik changes on code comments to be consistent with the launch of new Anaire PiCO2 device and documentation update on Guthub. First major upgrade.
// 20210307 Fixed remoted updates by reducing BearSSL buffer size
// 20210304 Troubleshooting remote updates after enabling serial debug; display modified to show ppm in 16p before ppm value on 24p font
// 20210228 Fixed execution of individual MQTT commands; firmware updates work if Wifi connection is fast
// 20210223 Fixed MQTT error problem when Wifi didn't connect on the first try
// 20210221 Range of Winsen MH-Z14A/MH-Z19c set up to 2000ppm as it is enough to secure environments against COVID and provides more accuracy
// 20210221 The CO2 measurement sent by MQTT every MQTT loop (30s) is calculated as the mean of the measured values during the measurement loop (5s)
//////////////////////////////////////////////////////////////////////////////////////////////////////////////////////////////////////////////////////////////////////////////////////////////////////////////////////

// device id, automatically filled by concatenating the last three fields of the wifi mac address, removing the ":" in betweeen
// i.e: ChipId (HEX) = 85e646, ChipId (DEC) = 8775238, macaddress = E0:98:06:85:E6:46
String anaire_device_id = String(ESP.getChipId(), HEX);   // HEX version, for easier match to mac address

// The neatest way to access variables stored in EEPROM is using a structure
// Init to default values; if they have been chaged they will be readed later, on initialization
struct MyEEPROMStruct {
  char anaire_device_name[24] = "";                           // Device name; default to anaire_device_id
  uint16_t CO2ppm_warning_threshold = 700;                    // Warning threshold; default to 700ppm
  uint16_t CO2ppm_alarm_threshold = 1000;                     // Alarm threshold; default to 1000ppm
  char MQTT_server[24] = "mqtt.anaire.org";                   // MQTT server url or public IP address. Default to Anaire Portal on portal.anaire.org
  uint16_t MQTT_port = 80;                                    // MQTT port; Default to Anaire Port on 30183
  boolean sound_alarm = true;                                 // Global flag to control sound alarm; default to true
  boolean ABC = false;                                        // Automatic baseline Correction; default to false
  uint16_t FRC_value = 400;                                   // Forced ReCalibration value; default to 400ppm
  uint16_t temperature_offset = 0;                            // temperature offset for SCD30 CO2 measurements
  uint16_t altitude_compensation = 0;                         // altitude compensation for SCD30 CO2 measurements
  char wifi_user[24] = "";                                    // WiFi user to be used on WPA Enterprise. Default to null (not used)
  char wifi_password[24] = "";                                // WiFi password to be used on WPA Enterprise. Default to null (not used)
} eepromConfig;

// Save config values to EEPROM
#include <ESP_EEPROM.h>

// Measurements loop: time between measurements
unsigned int measurements_loop_duration = 5000;   // 5 seconds
unsigned long measurements_loop_start;            // holds a timestamp for each control loop start

// MQTT loop: time between MQTT measurements sent to the cloud
unsigned int MQTT_loop_duration = 30000;          // 30 seconds
unsigned long MQTT_loop_start;                    // holds a timestamp for each cloud loop start
unsigned long lastReconnectAttempt = 0;           // MQTT reconnections

// Errors loop: time between error condition recovery
unsigned int errors_loop_duration = 3000;         // 3 seconds
unsigned long errors_loop_start;                  // holds a timestamp for each error loop start

// flash button duration: time since flash button was pressed
unsigned long flash_button_press_start;            // holds a timestamp for each control loop start

// CO2 Blinking period, used to reflect CO2 status on builtin led and buzzer
const int WARNING_BLINK_PERIOD = 1000;            // 1 second
const int ALARM_BLINK_PERIOD = 200;               // 0.2 seconds

// For http binary updates
#include <ESP8266HTTPClient.h>
#include <ESP8266httpUpdate.h>

// WiFi
#include <ESP8266WiFi.h>                          // Wifi ESP8266
extern "C" {
#include "user_interface.h"
#include "wpa2_enterprise.h"
#include "c_types.h"
}

#include <ESP8266WiFiMulti.h>
#include <ESP8266mDNS.h>                         // to be reached on anaire_device_id.local in the local network
WiFiClient wifi_client;
const int WIFI_CONNECT_TIMEOUT = 5000;           // 5 seconds
int wifi_status = WL_IDLE_STATUS;
WiFiServer wifi_server(80);                      // to check if it is alive
String wifi_ssid = WiFi.SSID();                  // your network SSID (name)
String wifi_password = WiFi.psk();               // your network psk password

#include <ESP8266WebServer.h>
#include <DNSServer.h>
#include <WiFiManager.h>
#include <DoubleResetDetector.h>

// Number of seconds after reset during which a subseqent reset will be considered a double reset.
#define DRD_TIMEOUT 10

// RTC Memory Address for the DoubleResetDetector to use
#define DRD_ADDRESS 0
DoubleResetDetector drd(DRD_TIMEOUT, DRD_ADDRESS);

// Indicates whether ESP has WiFi credentials saved from previous session, or double reset detected
bool initialConfig = false;

// OLED ssd1306 screen
#include <Wire.h>
#include "SSD1306Wire.h"

// SCL and SDA pin connections
#define OLED_SCK_GPIO 14  // signal GPIO14 (D5)
#define OLED_SDA_GPIO 12  // signal GPIO12 (D6)

// for 128x32 displays:
SSD1306Wire display(0x3c, OLED_SDA_GPIO, OLED_SCK_GPIO, GEOMETRY_128_32);  // ADDRESS, SDA, SCL

// MQTT
#include <PubSubClient.h>
char MQTT_message[256];
String MQTT_send_topic = "measurement";
String MQTT_receive_topic = "config/" + anaire_device_id;  // config messages will be received in config/id
PubSubClient MQTT_client(wifi_client);
char received_payload[384];

//JSON
#include <ArduinoJson.h>
StaticJsonDocument<384> jsonBuffer;

// Sensirion SCD CO2, temperature and humidity sensor
#define SCD30WIRE Wire
#include "paulvha_SCD30.h"
#define SCD30_SCK_GPIO 14 // signal GPIO14 (D5)
#define SCD30_SDA_GPIO 12 // signal GPIO12 (D6)

SCD30 airSensor;
unsigned long SCD30_WARMING_TIME = 2000;                                // SCD30 CO2 sensor warming time
unsigned long SCD30_CALIBRATION_TIME = 180000;                          // SCD30 CO2 CALIBRATION TIME: 3 min = 180000 ms
uint16_t SCD30_MEASUREMENT_INTERVAL = measurements_loop_duration / 1000; // time between measurements

// MHZ14A CO2 sensor: software serial port
#include "SoftwareSerial.h"                            // Remove if using HardwareSerial or non-uno compatabile device
#include "MHZ19.h"                                     // https://github.com/WifWaf/MH-Z19 Library
MHZ19 myMHZ19;
#define MHZ_BAUDRATE 9600                              // Native to the sensor (do not change)
const unsigned long MHZ14A_WARMING_TIME = 180000;      // MHZ14A CO2 sensor warming time: 3 minutes = 180000 ms
const unsigned long MHZ14A_SERIAL_TIMEOUT = 3000;      // MHZ14A CO2 serial start timeout: 3 seconds = 3000 ms
const unsigned long MHZ14A_CALIBRATION_TIME = 1200000; // MHZ14A CO2 CALIBRATION TIME: 20 min = 1200000 ms
#define swSerialRX_gpio 13
#define swSerialTX_gpio 15
SoftwareSerial mySerial(swSerialRX_gpio, swSerialTX_gpio);
byte measurement_command[9] = {0xFF, 0x01, 0x86, 0x00, 0x00, 0x00, 0x00, 0x00, 0x79};  // Command to get measurements from MHZ14A CO2 sensor
byte calibration_command[9] = {0xFF, 0x01, 0x87, 0x00, 0x00, 0x00, 0x00, 0x00, 0x78};  // Command to calibrate MHZ14A CO2 sensor
char response_CO2[9];   // holds the received data from MHZ14A CO2 sensor
int response_CO2_high;  // holds upper byte
int response_CO2_low;   // holds lower byte

int CO2ppm_value = 0;         // CO2 ppm measured value
int CO2ppm_accumulated = 0;   // Accumulates co2 measurements for a MQTT period
int CO2ppm_samples = 0;       // Counts de number of samples for a MQTT period

// AZ-Delivery DHT11
#include "DHTesp.h"
#define DHT_GPIO 5      // signal GPIO5 (D1)

// Initialize DHT sensor
DHTesp dht;
float temperature;      // Read temperature as Celsius
float humidity;         // Read humidity in %

// AZ-Delivery Active Buzzer
#define BUZZER_GPIO 4   // signal GPIO4 (D2)

// GPIO0 (D3) is button FLASH on nodemcu PCB
#define FLASH_BUTTON_GPIO 0
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
void loop() {

  // If a firmware update is in progress do not do anything else
  if (!updating) {

    //Serial.println ("--- LOOP BEGIN ---");

    // Measurement loop
    if ((millis() - measurements_loop_start) >= measurements_loop_duration)
    {

      // New timestamp for the loop start time
      measurements_loop_start = millis();

      // Read sensors
      Read_Sensors();

      // Evaluate CO2 value
      Evaluate_CO2_Value(); // this is to avoud to refresh the display with the las co2 measurement value

      // Accumulates samples
      CO2ppm_accumulated += CO2ppm_value;
      CO2ppm_samples++;

    }

    // MQTT loop
    if ((millis() - MQTT_loop_start) >= MQTT_loop_duration)
    {

      // New timestamp for the loop start time
      MQTT_loop_start = millis();

      // Message the MQTT broker in the cloud app to send the measured values
      if (!err_wifi) {
        Send_Message_Cloud_App_MQTT();
      }

      // Reset samples
      CO2ppm_accumulated = 0;
      CO2ppm_samples = 0;

    }

    // if FLASH button was pressed flag to updated OLED was set; the display cannot be updated from the ISR, but from main loop after this flag is set
    if (((update_OLED_co2_flag) && ((millis() - flash_button_press_start)) > 3000)) { // do it only if button was pressed more than 3s ago
      update_OLED_CO2();
      update_OLED_co2_flag = false; // reset flag
    }

    // if FLASH button was pressed flag to updated OLED was set; the display cannot be updated from the ISR, but from main loop after this flag is set
    if (update_OLED_status_flag) {
      update_OLED_Status();
      update_OLED_status_flag = false; // reset flag
    }

    // if the flash button was pressed more than 10 seconds ago and it is still low, launch calibration
    if (digitalRead(FLASH_BUTTON_GPIO)) { // button not pressed
      flash_button_pressed_flag = false; // reset flash button press start
    }
    else if ((millis() - flash_button_press_start) > 10000) {   // button is pressed since >10s
      if (co2_sensor == MHZ14A) {
        Calibrate_MHZ14A();
      }
      if (co2_sensor == SCD30) {
        Calibrate_SCD30();
      }
    }

    // Call the double reset detector loop method every so often,so that it can recognise when the timeout expires.
    // You can also call drd.stop() when you wish to no longer consider the next reset as a double reset.
    drd.loop();

    // Process wifi server requests
    Check_WiFi_Server();

    // Errors loop
    if ((millis() - errors_loop_start) >= errors_loop_duration)
    {

      // New timestamp for the loop start time
      errors_loop_start = millis();

      // Try to recover error conditions
      if (err_co2) {
        Serial.println ("--- err_co2");
        Setup_sensors();  // Init co2 sensors
      }

      if ((err_wifi) || (WiFi.status() != WL_CONNECTED)) {
        Serial.println ("--- err_wifi");
        err_wifi = true;
        Connect_WiFi();   // Attempt to connect to WiFi network:
      }

      //Reconnect MQTT if needed
      if ((!MQTT_client.connected()) && (!err_wifi)) {
        Serial.println ("--- err_mqtt");
        err_MQTT = true;
      }

      //Reconnect MQTT if needed
      if ((err_MQTT) && (!err_wifi)) {
        Serial.println ("--- MQTT reconnect");
        // Attempt to connect to MQTT broker
        //MQTTReconnect();
        Init_MQTT();
      }

      // if not there are not connectivity errors, receive MQTT messages
      if ((!err_MQTT) && (!err_wifi)) {
        MQTT_client.loop();
      }

    }

    //Serial.println("--- END LOOP");
    //Serial.println();

  }

}

///////////////////////////////////////////////////////////////////////////////////////////////////
// FUNCTIONS
///////////////////////////////////////////////////////////////////////////////////////////////////

// Connect to WiFi network
void Connect_WiFi() {

  Serial.print("Attempting to connect to Network named: ");
  Serial.println(wifi_ssid); // print the network name (SSID);

  // Set wifi mode
  WiFi.mode(WIFI_STA);

  // If there are not wifi user and wifi password defined, proceed to traight forward configuration
  if ((strlen(eepromConfig.wifi_user) == 0) && (strlen(eepromConfig.wifi_password) == 0)) {

    //WiFi.begin(wifi_ssid, wifi_password);
    WiFi.begin();

  }

  else {  // set up wpa2 enterprise

    Serial.print("Attempting to authenticate with WPA Enterprise ");
    Serial.print("User: ");
    Serial.println(eepromConfig.wifi_user);
    Serial.print("Password: ");
    Serial.println(eepromConfig.wifi_password);

    // Setting ESP into STATION mode only (no AP mode or dual mode)
    wifi_set_opmode(STATION_MODE);

    struct station_config wifi_config;

    memset(&wifi_config, 0, sizeof(wifi_config));
    strcpy((char*)wifi_config.ssid, wifi_ssid.c_str());
    strcpy((char*)wifi_config.password, wifi_password.c_str());

    wifi_station_set_config(&wifi_config);
    //uint8_t target_esp_mac[6] = {0x24, 0x0a, 0xc4, 0x9a, 0x58, 0x28};
    //wifi_set_macaddr(STATION_IF,target_esp_mac);
    wifi_station_set_wpa2_enterprise_auth(1);

    // Clean up to be sure no old data is still inside
    wifi_station_clear_cert_key();
    wifi_station_clear_enterprise_ca_cert();
    wifi_station_clear_enterprise_identity();
    wifi_station_clear_enterprise_username();
    wifi_station_clear_enterprise_password();
    wifi_station_clear_enterprise_new_password();

    // Set up authentication
    //wifi_station_set_enterprise_identity((uint8*)eepromConfig.wifi_user, strlen(eepromConfig.wifi_user));
    wifi_station_set_enterprise_username((uint8*)eepromConfig.wifi_user, strlen(eepromConfig.wifi_user));
    wifi_station_set_enterprise_password((uint8*)eepromConfig.wifi_password, strlen((char*)eepromConfig.wifi_password));

    wifi_station_connect();

  }

  // Timestamp for connection timeout
  int wifi_timeout_start = millis();

  // Wait for warming time while blinking blue led
  while ((WiFi.status() != WL_CONNECTED) && ((millis() - wifi_timeout_start) < WIFI_CONNECT_TIMEOUT)) {
    delay(500); // wait 0.5 seconds for connection
    Serial.print(".");
  }

  // Status
  if (WiFi.status() != WL_CONNECTED) {
    err_wifi = true;
  }
  else {
    err_wifi = false;

    wifi_server.begin(); // start the web server on port 80
    Serial.println("WiFi connected");
    Serial.print("IP address: ");
    Serial.println(WiFi.localIP());

    // Print your WiFi shield's MAC address:
    Serial.print("MAC Adress: ");
    Serial.println(WiFi.macAddress());

    // Set mDNS to anaire_device_id.local
    if (!MDNS.begin(String(anaire_device_id))) {
      Serial.println("Error mDNS");
    }
    else {
      Serial.print("Hostname: ");
      Serial.print(String(anaire_device_id));
      Serial.println(".local");
    }

  }

}

void Init_MQTT() {
  Serial.print("Attempting to connect to the MQTT broker ");
  Serial.print(eepromConfig.MQTT_server);
  Serial.print(":");
  Serial.println(eepromConfig.MQTT_port);

  // Attempt to connect to MQTT broker
  MQTT_client.setBufferSize(512); // to receive messages up to 512 bytes length (default is 256)
  MQTT_client.setServer(eepromConfig.MQTT_server, eepromConfig.MQTT_port);
  MQTT_client.setCallback(Receive_Message_Cloud_App_MQTT);
  MQTT_client.connect(anaire_device_id.c_str());

  if (!MQTT_client.connected()) {
    err_MQTT = true;
    MQTTReconnect();
  }
  else {
    err_MQTT = false;
    lastReconnectAttempt = 0;
    // Once connected resubscribe
    MQTT_client.subscribe(MQTT_receive_topic.c_str());
    Serial.print("MQTT connected - Receive topic: ");
    Serial.println(MQTT_receive_topic);
  }

}
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

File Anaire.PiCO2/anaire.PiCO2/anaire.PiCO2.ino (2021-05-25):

//////////////////////////////////////////////////////////////////////////////////////////////////////////////////////////////////////////////////////////////////////////////////////////////////////////////////////
// Anaire PiCO2 - Open CO2, temperature and humidity measurement device connected to Cloud Application www.anaire.org
// 202105 anaire.org anaire@anaire.org
//////////////////////////////////////////////////////////////////////////////////////////////////////////////////////////////////////////////////////////////////////////////////////////////////////////////////////
//
// HW Parts:
//   Control board: LILYGO® TTGO T-Display ESP32 WiFi And Bluetooth https://github.com/Xinyuan-LilyGO/TTGO-T-Display
//   Sensirion SCD30 CO2 temp and humidity sensor https://www.sensirion.com/en/environmental-sensors/carbon-dioxide-sensors/carbon-dioxide-sensors-scd30/
//   Buzzer: AZDelivery Active Buzzer - https://www.az-delivery.de/es/products/buzzer-modul-aktiv?_pos=2&_sid=39cea0af6&_ss=r
//   3D Box designed by Anaire: https://www.thingiverse.com/thing:4854504
//   3.7V lithium battery with JST Connector 2Pin 1.25mm, ex. https://www.amazon.es/dp/B087LTZW61/ref=cm_sw_r_cp_awdb_imm_BPVY2QA8X3P5GB9NQ55C
//
// SW Setup:
//   Install the usb to uart driver from https://www.silabs.com/developers/usb-to-uart-bridge-vcp-drivers
//   Setup the Arduino IDE for the ESP32 platform: https://github.com/espressif/arduino-esp32
//     Start Arduino and open Preferences window
//     Enter https://raw.githubusercontent.com/espressif/arduino-esp32/gh-pages/package_esp32_dev_index.json into Additional Board Manager URLs field. You can add multiple URLs, separating them with commas.
//     Open Boards Manager from Tools-> Board menu and find esp32 platform and install the latest version.
//     Select "ESP32 Dev Module" board from Tools-> Board menu after installation
//     Select Tools-> Partition Scheme-> Minimal SPIFFS (1.9MB APP with OTA/190KB SPIFFS) 
//   Setup the required libraries:
//   - TTGO T-Display's Git: Download the code as zip https://github.com/Xinyuan-LilyGO/TTGO-T-Display/archive/master.zip
//     Extract it and copy the Folder TFT_eSPI to your Arduino library path (usually <your user>/Documents/Arduino in Windows)
//   - Install the following libraries from Arduino IDE, select Tools -> Library manager.
//       - Search for Adafruit SCD30 by Adafruit https://github.com/adafruit/Adafruit_SCD30 and install the library
//       - Search for WifiManager by tzapu,tablatronix https://github.com/tzapu/WiFiManager and install the library
//       - Search for PubSubClient by Nick O'Leary https://github.com/knolleary/pubsubclient and install the library
//       - Search for ArduinoJson by Benoît Blanchon https://github.com/bblanchon/ArduinoJson and install the library
//       - Search for Button2 by Lennart Hennings https://github.com/LennartHennigs/Button2 and install the library
//   - If you plan to activate bluetooth measurements, install the Sensirion Gadget BLE Arduino Library https://github.com/Sensirion/Sensirion_GadgetBle_Arduino_Library/releases
//     Download latest zip. In the Arduino IDE, select Sketch -> include Library -> Add .zip Library and select the downloaded .zip file
//
// Buttons design:
//   - Top button short click: info about the device
//   - Top button LONG click: toggles acoustic alarm; enabled by default
//   - Top button double click: sleep; click a button to wake up
//   - Top button triple click: starts captive portal 
//   - Bottom button short click: buttons usage
//   - Bottom button LONG click: performs CO2 sensor forced calibration 
//   - Bottom button double click: restart device
//   - Bottom button triple click: enables auto self calibration
//
// Most functions are available through buttons, the web server and the Anaire Cloud Application
//   - WiFi configuration is only available through the captive portal. Portal can be launched from bottom button double click, or from the web server  
//   - MQTT endpoint only available through captive portal and Anaire Cloud Application (after being initially connected)
//   - Forced calibration reference value change only available through Anaire Cloud Application
//   - Remote firmware upgrade only available through Anaire Cloud Application 
//
//////////////////////////////////////////////////////////////////////////////////////////////////////////////////////////////////////////////////////////////////////////////////////////////////////////////////////
String sw_version = "v3.20210520.Malik";
// v3.20210520.Malik - Changed voltage thresholds and binary remote upgrade, after changing github documentation and folders
// v3.20210515.Kamasi - Changes in buttons functionality; web server completed; bluetooth enabled/disabled by a precompiler directive
// v3.20210512.Canine - Minor fixes: WiFi error recovery corrected; restart and captive portal added to web server
// v3.20210510.Berenice - Minor fixes: alarm on/off message after pressing top button
// v3.20210509.Anita - Minor fixes (IES Ppe Felipe)
// v3.20210508.Lenora - CO2 measurements each 10s; MQTT message each 60s; Temperature offset 600 (celsius hundredths) and altitude compensation to 600m by default
// v3.20210506.EllaFitz - Bug fixes
// v3.20210506.AEOC - CO2 measurements each 30s, MQTT sending each 60s. SCD30 is not reset anymore after a reading failure
// v3.20210506.Bona - Added battery voltage measurement in the MQTT message
// v3.20210504.Alain - OTA updates
// v3.20210504.Parker - Icons for battery, wifi and alarm
// v3.20210503.Mingus - Lots of improvements, first fully functional version; MQTT commandes not yet tested
// v3.20210502.Madrid - Lots of additions: SCD30 full support, coherent display messages, complete buttons support, etc.
// v3.20210430.Kuti - Bluetooth commented out for later to get captive portal fully functional
// v3.20210425.Samba - First fully functional Anaire PiCO2 device on TTGo T-Display board, connected to Anaire Cloud App
//////////////////////////////////////////////////////////////////////////////////////////////////////////////////////////////////////////////////////////////////////////////////////////////////////////////////////

#define BLUETOOTH false // Set to true in case bluetooth is desired

// device id, automatically filled by concatenating the last three fields of the wifi mac address, removing the ":" in betweeen, in HEX format. Example: ChipId (HEX) = 85e646, ChipId (DEC) = 8775238, macaddress = E0:98:06:85:E6:46
String anaire_device_id;
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

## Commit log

2020-11-09 Add files via upload
    Version 0.1 - reading CO2 from MH-Z14A sensor and Arduino Due
2020-12-06 New version, using PCB Led and OLED display
2020-12-07 Added calibration from web server and mdns to be reachable on anaire_device_id.local (depending on the router)
2020-12-07 Added info about CO2 sensor calibration
2020-12-07 Updated calibration and temperature and humidity info on OLED display
2020-12-07 Añadida la dinformación de montaje en español
2020-12-09 3d BOX to host the device
    [anaire_protoboard_box_v01.FCStd, anaire_protoboard_box_v01.stl, anaire_protoboard_tape_v01.stl]
2020-12-13 More files structuring
    [Anaire Prototipo MH-Z14a.fzz, anaire_protoboard_box_v01.FCStd, anaire_protoboard_box_v01.stl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]
2020-12-13 Actualización
    [Anaire Prototipo MH-Z14a.fzz, anaire_protoboard_box_v01.FCStd, anaire_protoboard_box_v01.stl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]
2020-12-15 Compatibilidad para ambos sensores de CO2
2020-12-15 Primera versión compatible con los dos sensores, MH-Z14A y SCD30
2020-12-20 MQTT con otra librería, con la intención de ser bidereccional; EEPROM writing of config parameters
2020-12-22 Fixed data storage persistancy between reboots and remote http firmware update
    [anaire-device.NodeMCULuaAmicaV2.ino]
2020-12-26 config.h not needed anymore WiFi captive portal by pressing twice reset button
2021-01-02 Nuevas instrucciones en detalle para la versión 21.01
2021-01-02 En proceso de elaboración, cambios intermedios
2021-01-02 Más info
    [AnaireBreadMH-Z14A.fzz, AnaireSlimSCD30.fzz]
2021-01-03 Actualizando documentación
    [Anaire Prototipo MH-Z14a.fzz, Anaire30ppm_SCD30.fzz, Anaire50ppm_MHZ14A.fzz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]
2021-01-04 Más documentación
    [Anaire30ppm_SCD30.fzz, Anaire50ppm_MHZ14A.fzz]
2021-01-08 Calibracioón de sensores
2021-01-08 Updating calibration procediures, and other minor things
2021-01-09 Cambios en forced calibration para el SCD30 (calibración a la misma tasa de lectura que la aplicación)
2021-01-09 Including sw version and sensor details in web server
2021-01-09 SCD30 Auto self calibration enabled
2021-01-10 Fix problem in web server to obtain SCD30 config info
    [anaire-device.NodeMCULuaAmicaV2.ino]
2021-01-10 Actualización de la librería para utilizar el sensor SCD30, y otras mejoras de edición
2021-01-13 Update README.md
    Insert videos for Anaire50ppm, platform setup and software upload
2021-01-16 New MH-Z19x library, that is valid for MH-Z14A too; getting much more info from the sensor in the web server and serial monitor
2021-01-16 Disable ABC automatic calibration for MHZ14A/19x sensors and run the calibrate command after "calibration time" to allow the device to stabilize
    [anaire-device.NodeMCULuaAmicaV2.ino]
2021-01-16 SCD30 ABC Autoself calibration disabled
2021-01-16 Más cambios en el SCD30 para ir ajustando el comportamiento
2021-01-16 Force SCD30 calibration at 500
2021-01-17 SCD30 forced calibration to 400
2021-01-17 Aquí seguimos con el SCD30...
2021-01-17 Seguimos con el SCD30
2021-01-24 Binario con el uso de la EEPROM desactivado
2021-01-24 Nuevo binario v2.20210124.Arapahoe con la EEPROM desativada
2021-02-02 Binario actualizado a la v2.20200202.delaniene
2021-02-02 Commands to remote execute operations in a batch of devices by using MQTT
2021-02-02 v2: Versión 2!!!!!!!!!!! Múltiples cambios - De HW: nuevo cableado del display para compartir los pines con los del SCD30, y nuevo cableado del zumbador para poder desvincular las alarmas sonora y vi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
2021-02-02 Se sube la librería de paulvha modificada para el control del Sensirion SCD30
2021-02-03 Actualizados esquemas de conexiones
2021-02-03 Actualizados archivos fritzing y su representación gráfica para la versión v2
    [Anaire30ppm_SCD30.fzz, Anaire50ppm_MHZ14A.fzz]
2021-02-04 Cambios editoriales y corrección de alguna errata
2021-02-07 Añadido comando para la actualización con python y arduino-update
2021-02-23 Fixed MQTT error and WiFi/MQTT reconnections
    [anaire-device.NodeMCULuaAmicaV2.ino]
2021-03-07 Fixing remote update issues
    [anaire-device.NodeMCULuaAmicaV2.ino]
2021-04-01 Nuevo proyecto: anaire_ttgo_minimal_OO2 para montar un medidor de CO2, temp y humedad mínimo con TTGO T-Display y SCD30
2021-04-01 Añadido funcionamiento de los botones
2021-04-01 Librería Adafruit SCD30 Comportamiento de ambos botones
2021-04-01 Añadida vcalibración forzada a 420ppm y la posibilidad de volver a activar la autocalibración
2021-04-26 Added ArduinoJson library on the setup information
2021-04-27 Using Button2 library directly from the IDE
2021-04-30 Bluetooth commented, as it is incompatible with captive portal as it is
    [anaire.PiCO2.ino]
2021-05-02 Lots of additions: SCD30 full support, coherent display messages, complete buttons support, etc.
2021-05-03 Recolocados los valores en el display
2021-05-04 Add files via upload
    Added instructions to flash device directly with the Anaire PiCO2 binary file
2021-05-04 Removed anaire_ttgo_minimal_CO2 and reorganized the files
    [Anaire30ppm_SCD30.fzz, Anaire50ppm_MHZ14A.fzz]
2021-05-06 Errors corrected; battery voltage measurements sent
    [anaire.PiCO2.ino]
2021-05-06 CO2 each 30s, MQTT message each 60s. SCD30 sensor not reset when there is an error.
    [anaire.PiCO2.ino]
2021-05-06 Fixed MQTT error when no samples have been accumulated
    [anaire.PiCO2.ino]
2021-05-13 Fixed WiFi issue; added options to web server
    [anaire.PiCO2.ino]
2021-05-15 Changes in buttons functionality; web server completed; bluetooth enabled/disabled by a precompiler directive
2021-05-18 Added tool to flash binary to board
2021-05-20 Añadido el nuevo dispositivo PiCO2; modificado el anterior, Anaire 30/50ppm
    [Anaire30ppm_SCD30.fzz, Anaire50ppm_MHZ14A.fzz]
2021-05-21 Copiado el binario de NodeMCU en la ubicación antigua, para poder actualizar dispositivos con versión de SW inferior a v2.20210520.Malik
2021-05-21 Copiados los binarios en la carpeta src para poder actualizar en remoto dispositivos antiguos
2021-05-21 Actualizado el binario del PiCO2
2021-05-31 Cambios en gráfico de cabñeado del Anaire 30ppm
2021-06-19 Eliminado el directorio src, que ya no es necesario
2022-01-25 Sound alarm is not reset anymore after CO2 gets below 700ppm
    [anaire-device.NodeMCULuaAmicaV2.ino]
